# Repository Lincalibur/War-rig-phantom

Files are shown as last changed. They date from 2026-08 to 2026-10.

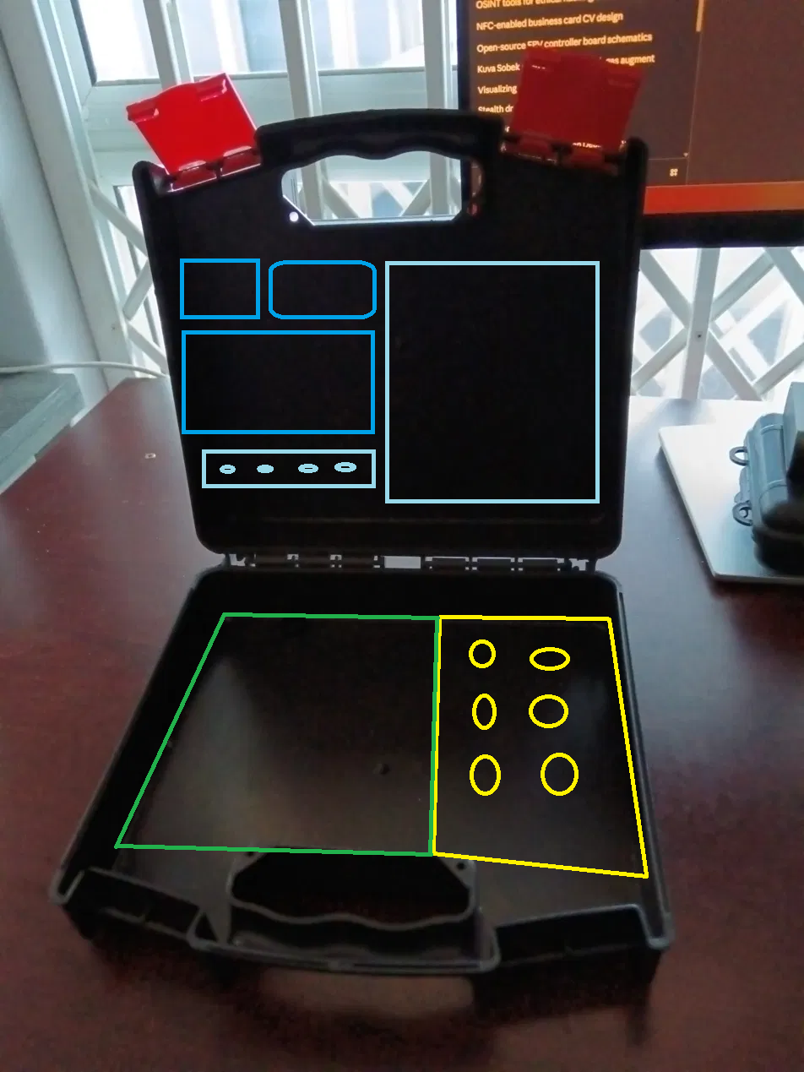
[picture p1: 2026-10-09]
docs/EmptyCase_Edit.png

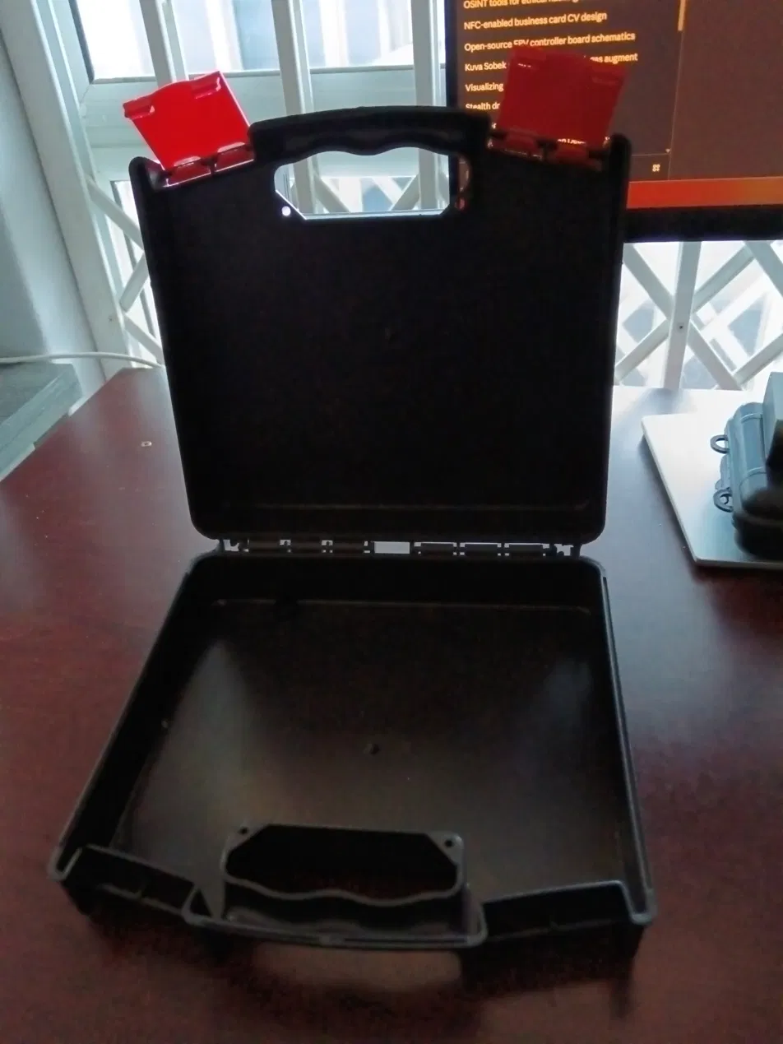
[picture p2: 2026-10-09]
docs/EmptyCase.webp

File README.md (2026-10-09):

<div align="center">

# War-rig-phantom
### *A Portable OPSEC/OSINT Recon Deck*

**Passive WiFi, BLE and sub-GHz listening with GPS-tagged logging, in a 22 cm clamshell case**






**[Build page](https://lincalibur.github.io/War-rig-phantom/)**: boards, case layout, parts checklist and wiring

</div>

---

## Overview

**War-rig-phantom** is a portable counter-surveillance deck built into a 22 × 22 cm clamshell case. Two receive-only ESP32 nodes (WiFi and BLE) and a CC1101 sub-GHz radio feed an ESP32-S3 hub, which logs WiGLE-format CSV to microSD and flags devices that keep following you. Each scan module has its own screen in the lid. A GPS module feeds both nodes, so every sighting carries its own position and time. It runs from a 2S2P 18650 pack. This is the budget v1 build; a Raspberry Pi 5 takes over as hub later.

> **Scope & Ethics**
> Everything in this project is **passive listening and logging.**
> - No deauth transmission
> - No packet injection
> - No touching networks you don't own
>
> This is a recon and awareness tool, not an attack platform.

## Architecture

```
  GPS (NEO-7M) TX --+--> WIFI-NODE  ESP32-C3 ---------------------UART--+
                    +--> BLE-SCAN   ESP32 + built-in 1.9" screen --UART--+
                                                                         v
                         HUB  ESP32-S3: microSD, CC1101 433 MHz, LED + piezo alerts
                                                                         |  row stream
                                                                         v
                         READOUT  Arduino UNO + 3.5" TFT (hub display)

  STATUS  ESP32-C3 + OLED (standalone counters)
  2S2P 18650 -> BMS -> fuse -> master switch -> 5 V buck -> one switch per module
```

The nodes never transmit. They report to the hub over wired UART, which fixes the timing and near-field interference problems that sank the v1 ESP-NOW design. Board names (`HUB`, `READOUT`, `BLE-SCAN`, `WIFI-NODE`, `STATUS`) are defined in [`docs/hardware-layout.md`](docs/hardware-layout.md#board-names).

## Repository

| Path | What's in it |
|---|---|
| [`docs/OVERVIEW.md`](docs/OVERVIEW.md) | **Start here.** Goals, decisions, capabilities, status and next steps |
| [`docs/hardware-layout.md`](docs/hardware-layout.md) | The current build: board names, case layout, power, wiring and parts list |
| [`docs/BOARD-BLE-SCAN-ESP32-1732S019.md`](docs/BOARD-BLE-SCAN-ESP32-1732S019.md) | Spec for the `BLE-SCAN` board |
| [`docs/build-page.html`](docs/build-page.html) | Source of the build page (deployed by `.github/workflows/pages.yml`) |
| [`docs/PCB-BOM-AND-NETLIST.md`](docs/PCB-BOM-AND-NETLIST.md), [`docs/esp32-hub-board.html`](docs/esp32-hub-board.html), [`KiCad Design/`](KiCad%20Design/) | Shelved single-PCB design. The S3 hub pin assignments are still used |
| [`v2/`](v2/README.md) | Firmware and bench prototypes (hub and nodes written, not yet compiled) |
| [`docs/debian-esp32-server-guide.md`](docs/debian-esp32-server-guide.md) | Remote compile/flash station over SSH |

The v1 build (ESP-NOW C3 nodes and an ESP32-1732S019 hub) was removed from the tree. Recover it with `git checkout v1-espnow-archive`.

## Status

| Area | State |
|---|---|
| Case layout and parts list | ✅ planned (2026-10-09); nde3d cart about R1,390 |
| Bench prototypes | ✅ WiFi readout working (C3 scanner to UNO + 3.5" TFT) |
| Power system | ⬜ parts to order; bench test first |
| Firmware | 🟨 hub and nodes written for the old PCB; need retargeting to the boards above, then a first compile |
| Raspberry Pi 5 hub | ⬜ later phase |

## License

See [LICENSE](LICENSE).

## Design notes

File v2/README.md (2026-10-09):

# CyberDeck v2 firmware

Firmware for the clamshell build (plan and wiring in [`../docs/hardware-layout.md`](../docs/hardware-layout.md)). Wired-UART architecture: two receive-only nodes report to an ESP32-S3 hub, and the hub draws on a UNO + 3.5" TFT.

> **Retarget pending.** `hub`, `node_wifi` and `node_ble` were written for the shelved single-PCB design (XIAO C5/C6 nodes, 2.8" ILI9341 on the hub) and have never been compiled. The table below says what each one has to become for budget v1.

## Boards and sketches

Board names are defined in [`../docs/hardware-layout.md`](../docs/hardware-layout.md#board-names).

| Board | Hardware | Sketch today | Work needed for budget v1 |
|---|---|---|---|
| `HUB` | ESP32-S3-DevKitC-1 N16R8 | `hub/` | Replace the ILI9341 UI with a row-stream sender for `READOUT`; add LED + piezo alerts; add CC1101 receive |
| `READOUT` | Arduino UNO R3 + 3.5" TFT shield | `proto_readout_uno/` (working) | None for display. Logging belongs on the `HUB` |
| `WIFI-NODE` | ESP32-C3 | `node_wifi/`; capture code proven in `proto_readout_c3/` | Retarget `node_wifi` to the C3: remove the C5-only band call, set the pins |
| `BLE-SCAN` | ESP32-1732S019 (built-in 1.9" ST7789) | `node_ble/`; detection logic in `proto_tracker_tripwire/` | Port to classic ESP32, add the ST7789 screen (LovyanGFX), prefer NimBLE. Spec: [`../docs/BOARD-BLE-SCAN-ESP32-1732S019.md`](../docs/BOARD-BLE-SCAN-ESP32-1732S019.md) |
| `STATUS` | ESP32-C3 + 128×64 OLED | none yet | New standalone sketch: counters on the OLED |

```
v2/
  shared/deck_link.h        wire protocol: framing, CRC, message structs (nodes + hub)
  shared/deck_node_core.h   node common code: GPS parser, tx queue, UART link, heartbeat
  node_wifi/node_wifi.ino   WIFI-NODE (target: ESP32-C3; code still XIAO C5)
  node_ble/node_ble.ino     BLE-SCAN (target: ESP32-1732S019; code still XIAO C6, no screen)
  hub/hub.ino               HUB, ESP32-S3: tables, WiGLE CSV logging to SD (UI still ILI9341)

  # Bench prototypes (spare parts, no custom PCB) — see "Bench prototypes" below
  proto_readout_c3/         ESP32-C3: WiFi-promiscuous scanner -> streams rows over UART
  proto_readout_uno/        Arduino UNO + 3.5" TFT: renders the readout (pairs with proto_readout_c3)
  proto_link_analyzer/      Arduino UNO: link diagnostic (byte/line/valid-frame stats) — bring-up tool
  proto_tracker_tripwire/   ESP32-S3 + ILI9341: standalone BLE tracker detector (unflashed; source for BLE-SCAN)
```

## Bench prototypes (2026-10-05)

Working counter-surveillance prototypes built from spare parts, independent of the custom PCB.
Wiring reference: [`../docs/proto-readout-wiring.html`](../docs/proto-readout-wiring.html).

**`proto_readout_c3` + `proto_readout_uno` — big-screen WiFi recon readout (WORKING).**
An ESP32-C3 (SuperMini) runs 802.11 promiscuous: APs (beacons/probe-resp), clients (probe-req +
data frames), deauth counting, channel hop 1-13. It keeps the tables and diffs the screen, then
streams `R<rr><c><text>` row-draw commands over a one-way 19200-baud UART to an Arduino UNO +
3.5" TFT, which is a dumb terminal (no tables -> the UNO's 2 KB RAM is never the limit). Clients
are sorted by **persistence** = the longest-shadowing unknown device is the "following me"
candidate. Flash the C3 first (`esp32:esp32:esp32c3:CDCOnBoot=cdc`), then the UNO
(`arduino:avr:uno`); unplug the C3->D0 wire while flashing the UNO.

**`proto_link_analyzer` — UNO link diagnostic.** Flash instead of the readout to measure the link:
bytes/s, lines, valid frames, control-byte (garbage) count, raw stream. Keep for future bring-up.

**`proto_tracker_tripwire` — standalone BLE tracker detector (UNFLASHED).** Runs on the S3 hub
board alone (2.8" ILI9341 + buzzer/LED) and flags AirTag/Find My/Tile/SmartTag by persistence.
BLE here uses Bluedroid; if it's flaky, switch to NimBLE (see learnings).

### Hard-won learnings from bring-up
- **AVR printf has no `*` (dynamic width) support.** `snprintf(..., "%-*.*s", COLS, COLS, s)` renders
  *nothing* on the UNO with no error — it silently broke `drawRow` across many rebuilds and looked
  like a link/power/C3 fault. Use literal widths on AVR: `"%-40.40s"`. (ESP32 printf is fine with `*`.)
- **Pace the UNO link.** The UNO's 64-byte hardware RX buffer overflows if the C3 bursts rows faster
  than the slow parallel TFT can paint them -> corrupted lines. The C3 waits ~150 ms between rows and
  does full refreshes rarely (15 s); normal updates send only the one changed status row.
- **BLE on the ESP32-C3 is unreliable** (Bluedroid + WiFi coexistence on the single radio crashes the
  chip). The C3's prototype role is WiFi-only. For BLE, prefer NimBLE or a separate chip (S3/H2).
- **C3 USB-CDC serial can't be captured** via `arduino-cli monitor` on the debian server — use the
  UNO link as the monitor instead.

## Status: hub and nodes written, NOT compiled, NOT flashed

The bench prototypes above run; `hub`, `node_wifi` and `node_ble` have never been built. Expect a round of compile fixes on the first build. In particular check:
- `esp_wifi_set_band_mode(WIFI_BAND_MODE_AUTO)` in `node_wifi.ino` is C5-only; remove it for the C3.
- The BLE API calls in `node_ble.ino` match your `esp32` core version (core 3.x vs 2.x differ slightly).
- All pin numbers (`DECK_LINK_*`, `DECK_GPS_RX_PIN`, hub `PIN_*`) against the real boards. Hub SPI, CC1101 and node-link pins are in section 3.1 of `../docs/PCB-BOM-AND-NETLIST.md`. Proposed, not yet in code: `WIFI-NODE` link TX=GPIO7, RX=GPIO6, GPS RX=GPIO20; `BLE-SCAN` link TX=GPIO17, RX=GPIO16, GPS RX=GPIO22; `HUB` readout TX=GPIO9, buzzer=GPIO18, alert LED=GPIO21.
- The hub's display pins (GPIO7-10), nav buttons (GPIO38-42) and VBAT sense (GPIO6) belong to the shelved PCB and are unused in this build.

## Build settings

| Sketch | FQBN (arduino-cli) | Notes |
|---|---|---|
| node_wifi | `esp32:esp32:esp32c3:CDCOnBoot=cdc` | `WIFI-NODE`, ESP32-C3. Remove the C5-only `esp_wifi_set_band_mode` call |
| node_ble | `esp32:esp32:esp32` | `BLE-SCAN`, ESP32-1732S019 ("ESP32 Dev Module", 4 MB flash, CH340). UART0 is the USB serial port on this board, so the link and GPS need UART1 and UART2 |
| proto_readout_uno | `arduino:avr:uno` | `READOUT`. Libraries: MCUFRIEND_kbv, Adafruit GFX |
| hub | `esp32:esp32:esp32s3:CDCOnBoot=cdc,PSRAM=opi` | ESP32-S3-DevKitC-1 N16R8 (octal PSRAM; GPIO33-37 unused) |

`CDCOnBoot=cdc` is required on the C3 node: hardware UART0 is used for the GPS, so `Serial` must be USB.

Hub libraries today: `Adafruit GFX Library`, `Adafruit ILI9341`. Both go away once the hub draws on `READOUT`.

## Bring-up order
0. **Power first**: bench-test the 2S pack, charger (8.4 V) and buck (5.1 V) before any board is connected. See `../docs/hardware-layout.md` section 5.
1. **Hub alone**: flash, confirm SD and the `READOUT` link, all pages render with zero data.
2. **One node at a time** on the bench: the node prints a status line over USB every 2 s; connect its UART to the hub and confirm the hub's status page shows LIVE and a non-zero fps.
3. **GPS**: connect the module's TX to both nodes, confirm `gps=fix` on a node's serial output outdoors, then `GPS FIX` on the hub header.
4. **Log check**: drive/walk a short loop, pull the SD, open `/wardrive/wigle_NNNN.csv`, and try a WiGLE upload.

## Wire protocol
See `shared/deck_link.h`. Frame `A5 5A | type | len | payload | crc16`. Nodes report each AP/client/BLE device when it is new, when its info changes, when it is heard ≥6–8 dB stronger, and every 30–45 s while still visible.

## Not implemented yet
- CC1101 sub-GHz (pins reserved on the hub; CS held high).
- LED + piezo alerts and the persistence ("following me") scoring on the hub.
- Pack voltage sensing. The 2S capacity indicator board is the only battery readout for now.
- 802.15.4 (Zigbee/Thread): no board in this build has that radio.

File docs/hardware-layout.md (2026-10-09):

# Hardware layout

Physical layout plan for the cyberdeck: a portable, passive counter-surveillance station built into a 22 × 22 cm clamshell case. Scan modules each run on their own screen in the lid, a hub coordinates them, and the base holds power, switching and the RF hardware.

The build is in two phases:

| Phase | Hub | Status |
|---|---|---|
| **Budget v1 (current)** | ESP32-S3-DevKitC-1 N16R8, using the 3.5" screen as its display | Parts in the nde3d cart, 2026-10-09 |
| **Later upgrade** | Raspberry Pi 5 + 5" display + USB hub + SDR | Deferred on cost; nde3d doesn't stock any of it |

Cyberdeck layout: lid, base and side section

> The drawing shows budget v1. In the Pi phase the blank plate becomes the 5" hub screen, and the two bays under the deck hold the Pi 5 and the USB hub + SDR.
>
> All dimensions are approximate planning figures. Measure the case interior and check every part against its datasheet before cutting anything.

---

## Board names

Every board has one fixed name. Use it in docs, firmware comments and on a label stuck to the board itself.

| Name | Board | Job | Reference |
|---|---|---|---|
| `HUB` | ESP32-S3-DevKitC-1 N16R8 | Brain: collects node reports, logs to SD, runs the CC1101, drives alerts | Pins: [`PCB-BOM-AND-NETLIST.md`](PCB-BOM-AND-NETLIST.md) section 3.1 |
| `READOUT` | Arduino UNO R3 + 3.5" TFT shield | Hub display (dumb terminal for the `HUB`) | [`proto-readout-wiring.html`](proto-readout-wiring.html) |
| `BLE-SCAN` | ESP32-1732S019 (classic ESP32 + built-in 1.9" screen) | Scan 2: BLE trackers | [`BOARD-BLE-SCAN-ESP32-1732S019.md`](BOARD-BLE-SCAN-ESP32-1732S019.md) |
| `WIFI-NODE` | ESP32-C3 (first one) | Headless WiFi promiscuous scanner | `v2/proto_readout_c3` |
| `STATUS` | ESP32-C3 (second one) + 128×64 OLED | Scan 3: status and counters | — |

---

## 1. Case

| Property | Value |
|---|---|
| Outer footprint | ~220 × 220 mm |
| Total height (closed) | ~70 mm |
| Depth per half | ~35 mm (lid and base are equal) |
| Handle recess | Top-centre of lid and front-centre of base, ~90 × 35 mm each |
| Hinge | Rear edge, full width |
| Anchor points | Moulded centre boss in each half |

**Usable interior per half:** roughly 205 × 165 mm once the handle recess and wall thickness are taken off.

---

## 2. Lid: displays and I/O

| Zone | Approx. size | Budget v1 | Later (Pi phase) |
|---|---|---|---|
| Top-left | 35 × 35 mm | 128×64 OLED + ESP32-C3: Scan 3, status/counters | Same |
| Top-middle | 55 × 40 mm | ESP32-1732S019 (built-in 1.9" 170×320): Scan 2, BLE trackers | Same |
| Middle-left | 85 × 56 mm | Arduino UNO + 3.5" TFT shield: **hub display**, fed by the S3 | Scan 1: main scan view |
| Bottom-left | ~117 × 22 mm | microSD shield slot, alert LED + piezo, mute button | Port panel: USB-A, USB-C, microSD |
| Right | ~77 × 121 mm | Empty (blank plate). GPS module mounts here, patch antenna facing out | 5" hub display, portrait |
| Hinge edge | ~25 mm strip | Cable slack zone | Same |

**Mounting:** a 3 mm faceplate with cut-outs for each screen, screwed to the lid's centre boss plus 4 corner standoffs (M3 nylon kit). Use acrylic or a 3D print, **not aluminium**: the ESP32 antennas sit behind the plate and metal would shield them.

**To measure before cutting:**
- The ESP32-1732S019 board outline against the 55 × 40 mm zone; the board is longer than its screen.
- The UNO + shield stack height. It is roughly 25–30 mm against the 23 mm lid budget in §4. It closes over the power zone, so keep that part of the deck clear.
- Feed the UNO through its 5 V pin. A USB-B plug won't fit behind the faceplate.

---

## 3. Base: power, switching and compute

### Top layer (deck plate)

| Zone | Contents |
|---|---|
| Rear strip | Hinge cable entry; CC1101 antenna (later: SMA jacks through the wall) |
| Left (green) | Power zone: master switch + panel fuse holder on top |
| Right (yellow) | Section switch panel: 6 mini toggles |
| Front-left pocket | Charge input: 5.5 × 2.1 mm DC jack (12 V in) |
| Front-centre | Handle recess (keep clear) |
| Front-right pocket | Battery capacity indicator (2S) |

### Below deck (electronics bay)

| Location | Budget v1 | Later (Pi phase) |
|---|---|---|
| Under power zone | 2S2P 18650 pack in a 4-cell holder, 2S BMS, 5 V buck, XL4015 charger | Same, plus a second buck for the lid rail |
| Under switch panel | Wiring only; keep ~15 mm clear for switch bodies | Same |
| Front-left bay | `HUB`: ESP32-S3 + CC1101 | Raspberry Pi 5 (85 × 56 mm), low-profile cooling |
| Front-right bay | `WIFI-NODE`: ESP32-C3 (headless) | Powered USB hub + SDR dongle |

Keep the CC1101 and the WiFi node away from the buck converter and the charger.

---

## 4. Depth budget (case closed)

When the case closes, the lid screens face down onto the deck, so both stacks must fit together.

| Layer | Thickness |
|---|---|
| Lid shell | 3 mm |
| ESP32 + driver boards | 15 mm |
| Screen modules | 8 mm |
| Gap to lid rim | 9 mm |
| *— split line —* | |
| Space above deck | 7 mm |
| Deck plate | 3 mm |
| Electronics bay | 22 mm |
| Base floor | 3 mm |
| **Total** | **~70 mm** |

The deck sits 3 mm higher than first drawn: an 18650 in a holder is about 21 mm tall and did not fit the original 19 mm bay.

**Rule:** switch caps + screen bezel protrusion must stay under ~16 mm combined, or the lid won't close.

---

## 5. Systems

### Power (budget v1)

```
12 V adapter ─► DC jack ─► XL4015 CC/CV (8.4 V, ~1 A) ─┐
                                                       ▼
18650 2S2P pack ◄─► 2S 20 A BMS ─► Fuse (8 A) ─► Master switch ─► 5 A buck (5.1 V) ─┬─► Hub (S3 + SD + CC1101 + GPS)
        │                                                                          ├─► Hub display (UNO + 3.5")
        └─► Capacity indicator (2S)                                                ├─► Scan 2 (ESP32-1732S019)
                                                                                   ├─► Scan 3 (C3 + OLED)
                                                                                   ├─► WiFi node (C3)
                                                                                   └─► Aux
```

- Load is about 1–1.5 A at 5 V, so the single buck runs everything. Runtime should be roughly 3–4 hours; measure it, because the cells are probably below their labelled 2200 mAh.
- Each branch has its own section switch so unused modules draw nothing.
- **Before connecting anything:** check the 4-cell holder with a multimeter and rewire it to 2S2P if it arrives as 4S (~15 V). Set the XL4015 to 8.4 V and the buck to about 5.1 V with no load.
- Charging is through the DC jack only. The single-cell USB-C charge/boost boards (IP5310, 5 V 2 A) **must never be connected to this pack**.
- The DC jack is rated 3 A; keep the XL4015 current limit at about 1 A.

**Pi phase changes:** the Pi 5 gets the 5 A buck to itself and the lid modules get a second buck. Add a momentary shutdown button on the Pi's power header (cutting power corrupts the SD card), set `usb_max_current_enable=1`, and confirm the master switch is rated 5 A DC or more.

### Section switch map

| Switch | Budget v1 | Later (Pi phase) |
|---|---|---|
| Master (power zone) | Everything, after the fuse | Same |
| 1 | Hub: S3 + SD + CC1101 + GPS | Pi 5 + 5" screen |
| 2 | Hub display: UNO + 3.5" TFT | Scan 1 |
| 3 | Scan 2: ESP32-1732S019 | Scan 2 |
| 4 | Scan 3: C3 + OLED | Scan 3 |
| 5 | WiFi node: C3 | RF/SDR: USB hub + SDR |
| 6 | Aux (spare) | Aux |

### Data (budget v1)

```
NEO-7M GPS TX ─┬─► WIFI-NODE (ESP32-C3) ──UART──┐
               └─► BLE-SCAN (ESP32-1732S019) ─UART─┴─► HUB (ESP32-S3) ──row stream (one-way UART)──► READOUT (UNO + 3.5" TFT)
                                                            │
                                                            ├─ SPI: microSD shield (logging), CC1101 (433 MHz)
                                                            └─ LED + piezo alerts, mute button
```

- All links are wired 3.3 V UART; nodes are receive-only radios. Framing is `v2/shared/deck_link.h`. S3 pins follow section 3.1 of [`PCB-BOM-AND-NETLIST.md`](PCB-BOM-AND-NETLIST.md).
- The hub display reuses the `R<rr><c><text>` row-stream protocol from `v2/proto_readout_c3` / `proto_readout_uno`; the S3 takes over the sender role from the C3.
- The GPS TX line fans out to both nodes, as the existing node firmware expects (`v2/shared/deck_node_core.h`): each node stamps its own sightings and the `HUB` takes position and time from their reports.
- The S3's three hardware UARTs are one per node link plus one for the `READOUT` stream. `STATUS` (C3 + OLED) runs standalone in v1; the `READOUT` UART's unused RX pin is free if it later needs a link.
- Put a ~1 kΩ series resistor on each UART line between separately switched modules, so a powered board can't back-feed an unpowered one through its I/O pins.
- The CH340E USB-TTL adapter is a bring-up tool: it captures C3 serial output (C3 USB-CDC capture has been unreliable) and later connects the GPS to the Pi.

**Pi phase changes:** the ESP32s connect to the Pi over USB serial through a powered hub. A board on the hub is powered through its USB cable, so section switches must then switch each cable's VBUS line (or use a hub with per-port switches) rather than a separate 5 V feed.

### RF and antennas

- Everything is passive receive. No deauth, injection or jamming.
- CC1101 (433 MHz) uses its spring antenna or an IPEX lead to the rear wall.
- GPS patch antenna faces out of the lid, away from the buck and charger.
- Later: SMA bulkhead jacks for the SDR. Fit them to a side wall if antennas would foul the open lid.
- Optional: copper tape shield over the buck converter.

### Thermal

Budget v1 needs no cooling. For the Pi phase the official active cooler is borderline in the bay; use a low-profile heatsink case or mount the Pi on the floor with the cooler through a deck cut-out, and cut a small vent grille near it.

---

## 6. Cable routing across the hinge

Only these should cross the hinge:

1. Switched 5 V feeds and ground to the lid modules
2. UART lines (BLE node → hub, hub → display)
3. GPS, SD and alert wiring, if those sit in the lid

Use the 10 mm mesh sleeve, leave a slack loop in the lid's hinge strip, and strain-relieve both ends. SPI to the SD shield is the one fast bus; keep that run short or mount the shield in the base.

---

## 7. Parts list

### 7.1 On hand

| Part | Role |
|---|---|
| Arduino UNO R3 + 3.5" 480×320 TFT shield | Hub display |
| ESP32-1732S019 (ESP32 + 1.9" ST7789) | Scan 2, BLE |
| ESP32-C3 ×2 | WiFi node; Scan 3 |
| 128×64 OLED | Scan 3 |
| Active/passive buzzers, LEDs, 12 mm push buttons | Alerts and mute |
| Master switch (toolbox spare) | Check rating before the Pi phase |
| Second UNO, breadboards, jumpers, resistors | Bring-up |

### 7.2 nde3d cart (2026-10-09)

| Part | Qty | Price | Role |
|---|---|---|---|
| [ESP32-S3-DevKitC-1 N16R8](https://nde3d.co.za/esp-devices/3511-esp32-s3-n16r8-devkitc-development-board-with-wireless-53-16mb-flash-8mb-ram-type-c-usb.html) | 1 | R188.86 | Hub |
| [CC1101 433 MHz, IPEX](https://nde3d.co.za/rf-modules/2959-433mhz-cc1101-wireless-rf-transceiver-module.html) | 1 | R114.00 | Sub-GHz receive |
| [GY-NEO-7M GPS](https://nde3d.co.za/rf-modules/3191-gy-neo-7m-gps-active-ceramic-antenna-module.html) | 1 | R136.48 | Position and time |
| [Micro TF/SD shield for D1 Mini](https://nde3d.co.za/modules/779-micro-tfsd-card-shield-for-d1-mini.html) | 1 | R24.00 | Logging |
| [CH340E Type-C USB-TTL](https://nde3d.co.za/interface-converters/971-ch340e-micro-usb-to-ttl-serial-converter-5v33v.html) | 1 | R42.00 | Bring-up; GPS to Pi later |
| [18650 2200 mAh Li-ion](https://nde3d.co.za/consumables/2977-37v-18650-1500mah-lithium-ion-battery.html) | 4 | R317.60 | 2S2P pack |
| [18650 holder ×4 with wires](https://nde3d.co.za/battery-holders/2635-18650-battery-holder-x4-with-wires.html) | 1 | R16.00 | Pack; rewire to 2S2P |
| [2S 20 A BMS](https://nde3d.co.za/interface-converters/2777-2s-20amp-battery-management-circuit-bms.html) | 1 | R75.00 | Protection + balancing |
| [5 A 75 W step-down module](https://nde3d.co.za/power-supplies/2428-5a-75w-dc-dc-high-power-adjustable-step-down-stabilized-voltage-supply-module.html) | 1 | R118.00 | 5 V rail |
| [XL4015 5 A CC/CV](https://nde3d.co.za/power-supplies/1258-5a-30v-adjustable-voltage-and-current-charger.html) | 1 | R66.00 | Charger, set to 8.4 V |
| [3 A 5.5 × 2.1 mm bulkhead DC connector](https://nde3d.co.za/plugs-sockets-connectors/2096-3a-55-x-21mm-bulkhead-male-dc-power-connector.html) | 1 | R4.67 | Charge input |
| [Fuse holder, 5×20 mm panel mount](https://nde3d.co.za/plugs-sockets-connectors/2499-fuse-holder-for-5x20mm-panel-mount.html) | 1 | R25.00 | Main fuse |
| [5×20 mm glass fuse 8 A](https://nde3d.co.za/fuses/2853-5-x-20mm-glass-fuse-250v-8a.html) | 5 | R15.00 | Main fuse + spares |
| [Miniature toggle SMTS-203 (DPDT)](https://nde3d.co.za/switches/2890-miniature-toggle-switch-on-off-on-smts-203-dpdt.html) | 6 | R84.00 | Section switches |
| [Capacity indicator board, 2S](https://nde3d.co.za/electronics/2574-12v-lithium-battery-power-indicator-board.html) | 1 | R58.00 | Battery meter |
| [Mesh nylon sleeve 10 mm × 1 m](https://nde3d.co.za/cable/3036-1-metre-flame-retardant-nylon-pet-mesh-telescopic-sleeve.html) | 1 | R7.00 | Hinge bundle |
| [M3 nylon standoff kit, 180 pcs](https://nde3d.co.za/bolts-nuts/3354-sdafasdf.html) | 1 | R98.78 | Mounting |
| **Total** | | **R1,390.39** | |

Also in the cart but **not used in this build** (single-cell boards, R116): IP5310 Type-C 3 A charge/boost module ×1, 5 V 2 A charge/boost module ×2.

### 7.3 Still needed for budget v1

- 12 V DC adapter with a 5.5 × 2.1 mm plug, 1 A or more
- 3 mm acrylic or printed faceplate and deck plate
- Hook-up wire (18–20 AWG for the power path), cable ties

### 7.4 Later (Pi phase, other suppliers)

| Part | Note |
|---|---|
| Raspberry Pi 5 + microSD + low-profile cooler | |
| 5" display, DSI touch preferred | Check outline against the 77 × 121 mm zone |
| Powered USB hub, 7+ ports | Per-port switches preferred |
| RTL-SDR, SMA bulkheads, pigtails, antennas | |
| Second 5 V buck | Lid rail |
| 2S USB-C charger module | Replaces DC-jack charging, optional |
| Shutdown push button | |
| nde3d: [USB-A panel extension](https://nde3d.co.za/plugs-sockets-connectors/1725-1mtr-usb-extension-cable-panel-mount-type-a.html) R33, [Type-C extension](https://nde3d.co.za/cable/3484-type-c-31-male-to-female-usb-extension-cable-with-screw-ear.html) R123, [microSD extender](https://nde3d.co.za/connectors/3513-microsd-card-extender.html) R84 | Port panel |

The Pi 5 has no 3.5 mm jack, so audio on the port panel would need a USB audio adapter.

---

## 8. Build order

- [ ] Measure the case interior precisely and update this doc
- [ ] Order the nde3d cart (§7.2)
- [ ] Make cardboard templates of the lid faceplate and base deck; test-fit with the case closed
- [ ] Build and test the power system on the bench: holder wiring, BMS, fuse, charger at 8.4 V, buck at 5.1 V, switches
- [ ] Bring up the S3 hub on the bench: SD, GPS, one node at a time, then the UNO display link
- [ ] Cut faceplate and deck plate; cut the DC jack and meter openings in the front pockets
- [ ] Mount the screens and modules; route the hinge bundle
- [ ] Full close test: confirm nothing touches when the lid shuts
- [ ] Walk test, log check, runtime measurement

---

## 9. Open questions

- Exact inner dimensions of each half
- Whether `STATUS` stays standalone or gets a link to the hub (one UART RX pin is free)
- Current rating of the SMTS-203 toggles (not in the listing); matters once a Pi draws 4–5 A through one
- Pi location when it arrives: base (as drawn) or behind the hub screen in the lid

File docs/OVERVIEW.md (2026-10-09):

# CyberDeck v2 — overview

Start here. This covers what the deck does, the hardware decisions and why they were made, and where everything else lives.

> **Current plan (2026-10-09): clamshell build, no custom PCB.** The deck is now a 22 × 22 cm clamshell case with one screen per scan module, hand-wired from modules. Budget v1 uses the ESP32-S3 as hub; a Raspberry Pi 5 replaces it later. The physical layout, power system, data links and parts list are in [`hardware-layout.md`](hardware-layout.md), which wins where it differs from this page. The single-PCB design described under "Board" below is shelved; its S3 pin assignments are still used.

| Need | Go to |
|---|---|
| **Current build: layout, power, wiring, parts list** | [`hardware-layout.md`](hardware-layout.md) |
| Board names (`HUB`, `READOUT`, `BLE-SCAN`, `WIFI-NODE`, `STATUS`) | [`hardware-layout.md`](hardware-layout.md#board-names) |
| `BLE-SCAN` board spec (ESP32-1732S019: pins, display config, build settings) | [`BOARD-BLE-SCAN-ESP32-1732S019.md`](BOARD-BLE-SCAN-ESP32-1732S019.md) |
| S3 hub pin assignments (and the shelved PCB BOM) | [`PCB-BOM-AND-NETLIST.md`](PCB-BOM-AND-NETLIST.md) |
| Build page on GitHub Pages: boards, layout, parts checklist, wiring | [`build-page.html`](build-page.html), deployed to <https://lincalibur.github.io/War-rig-phantom/> |
| Shelved single-PCB interactive page | [`esp32-hub-board.html`](esp32-hub-board.html) (deployed as `pcb-v2.html`) |
| KiCad project | [`../KiCad Design/`](../KiCad%20Design/) |
| Firmware, build settings, bring-up order | [`../v2/README.md`](../v2/README.md) |
| Remote flashing station | [`debian-esp32-server-guide.md`](debian-esp32-server-guide.md) |

The v1 ESP-NOW build (C3 nodes, ESP32-1732S019 hub) was removed from the tree. It is kept in git under the tag `v1-espnow-archive`.

## Goal
A portable counter-surveillance deck that scans and logs the radio environment around you and flags devices that keep following you: WiFi networks and devices, BLE devices and trackers, and sub-GHz signals. Every sighting is GPS-tagged. The case is a **22 × 22 × 7 cm clamshell**.

**Everything here is passive listening.** Don't add deauth, injection or jamming features.

## Architecture (budget v1)

```
  NEO-7M GPS TX --+--> WIFI-NODE (ESP32-C3) ----------UART--+
                  +--> BLE-SCAN (ESP32-1732S019, 1.9") -UART--+--> HUB (ESP32-S3) --row stream--> READOUT (UNO + 3.5" TFT)
  STATUS (ESP32-C3 + OLED, standalone)                              |  SPI: microSD, CC1101 433 MHz
                                                                    |  LED + piezo alerts
  2S2P 18650 -> BMS -> fuse -> master switch -> 5 V buck -> section switch per module
```

The GPS still fans out to both nodes, and the hub's display is the UNO + 3.5" shield already on hand. Details are in [`hardware-layout.md`](hardware-layout.md).

## Architecture (original single-PCB design, shelved)

```
                 GPS TX (NEO-7M) ------+----------------+
                                       |                |
                            +----------v-----+  +-------v--------+
                            | ESP32-C3 PRO   |  | ESP32-H2       |
                            | Mini: WiFi     |  | SuperMini: BLE |
                            | 2.4 GHz        |  | (+802.15.4)    |
                            +-------+--------+  +-------+--------+
                                    | UART              | UART   (wired, 3.3 V)
                            +-------v-------------------v--------+
                            |  ESP32-S3-DevKitC-1 N16R8 (hub)    |
                            |  SPI: 2.8" ILI9341, microSD,       |
                            |       CC1101 433 MHz               |
                            |  5-way nav, VBAT sense on GPIO6    |
                            +------------------------------------+
  18650 -> IP5310 board -> SW_PWR -> 5V_RAIL -> each module (via its own Schottky)
```

The key idea is that **nodes never transmit**. They are receive-only scanners that report over wired UART. That removes the ESP-NOW timing problems and the near-field desense that broke v1. Each node reads the GPS directly, so it tags its own sightings with position and time.

## Decisions

| Date | Decision | Why |
|---|---|---|
| 2026-09-20 | Fresh start as one KiCad PCB | The ESP-NOW build never worked reliably with both nodes active |
| 2026-09-20 | Wired UART instead of ESP-NOW | Nodes stay receive-only, so there's no timing or near-field interference |
| 2026-09-20 | ESP32-S3 hub with a separate 2.8" SPI TFT | More GPIO and RAM than the ESP32-1732S019, plus a bigger screen |
| 2026-09-20 | GPS fanned out to both nodes | Every sighting carries its own location |
| 2026-09-20 | CC1101 on the hub SPI bus | Replaces the faulty RXB6 sub-GHz receiver |
| 2026-09-20 | Ready-made power module, no custom charge/boost stage | Power is the part most likely to cause random resets |
| 2026-09-20 | WiGLE-format CSV on microSD | Uploadable to wigle.net |
| 2026-09-25 | Source everything from nde3d.co.za | One South African supplier. This forced the substitutions below |
| 2026-10-05 | Reposition as a counter-surveillance tool | "Am I being followed" scoring on top of the same passive radios; LED + piezo alerts |
| 2026-10-09 | 22 × 22 cm clamshell, one screen per scan module, no custom PCB | Bigger case on hand; modules and screens already owned; hand-wiring avoids a PCB order |
| 2026-10-09 | ESP32-S3 stays the hub for budget v1; Raspberry Pi 5 later | The Pi 5, 5" display, USB hub and SDR are too expensive for now and nde3d stocks none of them |
| 2026-10-09 | 2S2P 18650 + BMS + 5 V buck replaces the IP5310 single-cell stage | Sized so a Pi 5 can be added without rebuilding the power system. Charging is via a DC jack and an XL4015 at 8.4 V, because nde3d has no 2S USB-C charger |
| 2026-10-09 | No 2.8" ILI9341; the hub draws on the UNO + 3.5" shield | Saves R468 and reuses the working row-stream readout |

**nde3d substitutions (2026-09-25).** Full detail is in section 1.4 of `PCB-BOM-AND-NETLIST.md`.
- WiFi node: ESP32-C3 PRO Mini replaces the XIAO C5. That means **no 5 GHz**; most dual-band APs still beacon on 2.4 GHz.
- BLE node: ESP32-H2 SuperMini replaces the XIAO C6. If H2 BLE misbehaves in Arduino, fall back to a C3 SuperMini.
- Power: an IP5310 power-bank board plus an 18650 replaces the PowerBoost 1000C and LiPo. The IP5310 has no EN or LBO pin, so the power switch sits on the 5 V output and low battery comes from a VBAT divider on GPIO6.
- Buttons: a 5-way nav module replaces five tactile switches.
- GPS: NEO-7M. CC1101: 433 MHz for South Africa.

## What the radios can and can't do
- **WiFi (C3):** promiscuous mode captures management frames and data-frame headers. That covers APs (SSID, BSSID, channel, encryption, vendor, hidden SSIDs, RSSI), clients (MAC, probed SSIDs, random-MAC detection) and client-to-AP links. It listens on one channel at a time and hops. It's 2.4 GHz only.
- **BLE (H2):** advertisement scanning gives MAC, RSSI, name, manufacturer ID and tracker detection (AirTag / Find My / Tile). It can't do Classic Bluetooth. 802.15.4 (Zigbee/Thread) is possible later.
- **Sub-GHz (CC1101, 433 MHz):** OOK/ASK/FSK reception. Not implemented in firmware yet.
- **Not possible here:** true wideband spectrum analysis, LoRa decoding, ADS-B or cellular. Those need an RTL-SDR, which sits outside this board.

## Board (shelved)
The single-PCB design below is kept for reference. The current build is hand-wired in the clamshell case.

- **2 layers with a solid ground plane** on the bottom, never split. Everything is socketed: every module plugs into female headers so it can be swapped and reflashed.
- **Placement:** the hub and display go on the top face. The nodes, CC1101, IP5310 and battery go on the bottom face.
- **RF placement:** the GPS goes on the top edge with no copper under its patch. The WiFi and BLE nodes go at opposite short edges, with antenna keep-outs running to the board edge. The CC1101 antenna goes at an edge away from the nodes.
- **Power traces:** 5V_RAIL at least 1 mm wide, and at least 1.5 mm from the IP5310 to C1. Place each bulk cap right at the pin it feeds.
- **USB-C access:** every module's USB-C port must be reachable from the case edge for flashing.
- **Board size is not settled yet.** `PCB-BOM-AND-NETLIST.md` says 100 x 150 mm (portrait). The layout concept in `esp32-hub-board.html` is drawn at 170 x 100 mm. Pick one before routing.

## Power budget
These figures are for the shelved IP5310 design. The current power system is in [`hardware-layout.md`](hardware-layout.md) section 5; the 3.3 V note below still applies to the S3 hub.

- **5 V:** about 900 mA to 1 A peak (WiFi node ~250–300 mA, BLE node ~150 mA, S3 plus its 3V3 loads ~300–350 mA, display ~100 mA). The IP5310 board is rated 3.1 A. **The mini slide switch is the weak point:** many are rated only 0.3–0.5 A, so buy one rated 1 A or more.
- **3.3 V:** the S3 devkit's onboard LDO (~800 mA) feeds the display, GPS, CC1101 and SD, which puts it close to the limit at peak. If the hub browns out, give the display and SD their own 3.3 V regulator.
- Bench-test the IP5310 for charge-while-running (a possible brief dropout) and for idle auto-shutdown.

## Status (2026-10-09)
- **Hardware:** clamshell layout planned in `hardware-layout.md`; the nde3d cart for budget v1 (about R1,390) is listed there. The PCB and KiCad work are shelved.
- **Working on the bench:** the WiFi readout (`proto_readout_c3` + `proto_readout_uno`: C3 promiscuous scanner streaming rows to the UNO + 3.5" TFT).
- **Firmware** (`../v2/`): `hub`, `node_wifi` and `node_ble` are written but **never compiled or flashed**, and still carry XIAO C5/C6 pin labels. Needed for budget v1:
  - `hub.ino`: replace the ILI9341 UI with the row-stream sender for the UNO display; LED + piezo alerts.
  - `node_wifi`: retarget to the ESP32-C3 (remove the C5-only band call, remap pins).
  - BLE node: port to the ESP32-1732S019 with its ST7789 screen (start from `proto_tracker_tripwire`).
  - Not implemented yet: CC1101 reception, pack voltage sensing.

## Next steps
1. Order the cart; measure the case interior and make cardboard templates.
2. Bench-build and test the power system before it goes near the electronics (see `hardware-layout.md` section 5).
3. Get the hub compiling on the S3, then bring up SD, GPS, one node at a time, then the UNO display link.
4. Cut the faceplate and deck, mount everything, and do the close test.
5. Walk test and a WiGLE upload. Add the Raspberry Pi 5 phase when budget allows.

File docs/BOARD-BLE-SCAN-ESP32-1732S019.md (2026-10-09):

# BLE-SCAN board: ESP32-1732S019

**Deck name: `BLE-SCAN`.** This is the classic ESP32 board with the built-in 1.9" colour screen, bought from nde3d. In the deck it is the Scan 2 module: BLE tracker detection on its own screen, reporting to the `HUB` over UART. All board names are listed in [`hardware-layout.md`](hardware-layout.md#board-names).

Earlier notes also call this board "the ESP-32S with the attached screen" and "the prototype hub". It is the same board. It is **not** the hub any more; the hub is the ESP32-S3.

Source: nde3d's product sheet, kept as [`ESP32-1732S019_Datasheet.pdf`](ESP32-1732S019_Datasheet.pdf). The sections marked "deck" are this project's own choices.

## Specifications

| Item | Value |
|---|---|
| Microcontroller | ESP32-D0WD-V3, dual-core Xtensa LX6, up to 240 MHz |
| Flash | 4 MB |
| PSRAM | None |
| WiFi | 2.4 GHz 802.11 b/g/n |
| Bluetooth | Classic (BR/EDR) and BLE |
| Display | 1.9" IPS TFT, 170 × 320 px, non-touch |
| Display driver | ST7789, 4-wire SPI |
| USB | Type-C, CH340 USB-to-serial |
| Logic level | 3.3 V |
| Power input | 5 V via USB-C |
| Onboard extras | BOOT and EN buttons only. No SD slot |

This is the classic ESP32 version of the board, not the ESP32-S3 version.

## Display pins (fixed on the board)

| Signal | GPIO |
|---|---|
| SCLK | 14 |
| MOSI | 13 |
| MISO | not connected |
| CS | 15 |
| DC | 2 |
| RST | tied to EN (use -1 in software) |
| Backlight | 21 |

- **Backlight:** drive GPIO 21 high with a plain `digitalWrite`. Don't use PWM; it has a known issue on recent ESP32 cores.
- **Free GPIOs:** 4, 16, 17, 22, 25, 26, 27, 32, 33.
- **Never use GPIO 6–11:** they are the onboard flash.

## Deck wiring (planned)

| Function | GPIO | Connects to |
|---|---|---|
| Link TX | 17 | `HUB` BLE_LINK_RX (S3 GPIO1), through ~1 kΩ |
| Link RX | 16 | `HUB` BLE_LINK_TX (S3 GPIO2), through ~1 kΩ |
| GPS RX | 22 | NEO-7M TX (shared with `WIFI-NODE`) |
| 5 V | 5 V pin | Section switch 3 |
| GND | GND | Common ground |

GPIO 16/17 are the ESP32's default UART2 pins. The remaining free GPIOs (4, 25, 26, 27, 32, 33) are spare for a local alert LED, buzzer or button. These assignments are a plan and have not been wired or tested.

## Arduino build settings

| Setting | Value |
|---|---|
| Board | ESP32 Dev Module (`esp32:esp32:esp32`) |
| Flash size | 4 MB |
| Upload speed | 921600; drop to 115200 if uploads fail |
| Driver | CH340 |

If an upload fails with "Failed to connect / wrong boot mode": hold BOOT, tap EN, release BOOT, then upload again.

## Display library configuration

nde3d recommends LovyanGFX. The whole pin configuration lives in the sketch.

```cpp
#define LGFX_USE_V1
#include <LovyanGFX.hpp>

class LGFX : public lgfx::LGFX_Device {
  lgfx::Panel_ST7789 _panel;
  lgfx::Bus_SPI      _bus;
public:
  LGFX() {
    { auto c = _bus.config();
      c.spi_host   = SPI2_HOST;   // HSPI
      c.spi_mode   = 0;
      c.freq_write = 40000000;
      c.pin_sclk   = 14;
      c.pin_mosi   = 13;
      c.pin_miso   = -1;
      c.pin_dc     = 2;
      _bus.config(c); _panel.setBus(&_bus); }
    { auto c = _panel.config();
      c.pin_cs   = 15;
      c.pin_rst  = -1;            // reset tied to EN
      c.panel_width  = 170;
      c.panel_height = 320;
      c.offset_x = 35;            // 170-wide panel offset
      c.offset_y = 0;
      c.invert   = true;          // IPS panel
      c.rgb_order = false;
      _panel.config(c); }
    setPanel(&_panel);
  }
};
LGFX tft;

void setup() {
  pinMode(21, OUTPUT);
  digitalWrite(21, HIGH);         // backlight on
  tft.init();
  tft.setRotation(1);             // landscape, 320 x 170
  tft.fillScreen(TFT_BLACK);
  tft.setTextColor(TFT_WHITE);
  tft.drawString("Hello!", 10, 10);
}
void loop() {}
```

- If red and blue look swapped, change `rgb_order`.
- If the image is shifted sideways, adjust `offset_x`.

## Limits that matter for the deck

- **4 MB flash, no PSRAM:** keep device tables small, and prefer NimBLE over Bluedroid to save flash and RAM.
- **No SD slot:** it cannot log on its own; logging happens on the `HUB`.
- **No touch and no user buttons:** any input needs a button on a free GPIO.
- **Board outline is not in the product sheet.** Measure it before cutting the 55 × 40 mm lid zone.

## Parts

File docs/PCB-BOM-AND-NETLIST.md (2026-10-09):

# CyberDeck v2 — exact BOM and netlist (KiCad input)

> **Shelved 2026-10-09.** The build moved to a hand-wired 22 × 22 cm clamshell case with a 2S battery system; the current parts list is in [`hardware-layout.md`](hardware-layout.md) section 7. This PCB BOM (section 1) and power tree (section 2) no longer describe what is being built. **Still in use:** the S3 hub pin assignments in section 3.1 for SPI, microSD, CC1101 and the node UART links. The display, nav-button and GPIO6 VBAT-divider nets do not apply (the divider was sized for one cell; a 2S pack needs different values).

Authoritative parts list and pin-by-pin connections for the 100 x 150 mm board. Where any other doc differs from this one, **this file wins** (see `OVERVIEW.md` for the why). As of the 2026-09-25 nde3d revision, the node boards changed (C3 PRO Mini / H2 SuperMini), so the firmware in `../v2/` still has XIAO pin labels and needs updating to match.

Items marked **[VERIFY]** are footprint/pinout facts recalled from memory of the manufacturer's documentation. Check each against the datasheet or the physical board before sending the PCB to fabrication.

## 1. Components

**Revision 2026-09-25: sourced from nde3d.co.za (Next Dimension Electronics).** nde3d doesn't stock the XIAO C5/C6, the PowerBoost 1000C, LiPo pouch cells, 6x6 tactile switches or PTC fuses, so those were substituted. Section 1.4 says what changed and why. Prices are as nde3d listed them on 2026-09-25.

### 1.1 Modules (all plug into socket headers; nothing is soldered down)

| Ref | Part | Qty | Board-side footprint | Notes |
|---|---|---|---|---|
| U1 | ESP32-S3-DevKitC-1 **N16R8**, [nde3d](https://nde3d.co.za/esp-devices/3511-esp32-s3-n16r8-devkitc-development-board-with-wireless-53-16mb-flash-8mb-ram-type-c-usb.html) R188.86 | 1 | 2x 1x22 female 2.54 mm, rows ~22.86 mm apart **[VERIFY]** | Hub. The octal PSRAM uses GPIO33-37, which this netlist already leaves free. In Arduino, set PSRAM = "OPI PSRAM" |
| U2 | ESP32-C3 PRO Mini (ceramic antenna + IPEX), [nde3d](https://nde3d.co.za/esp-devices/3722-esp32-c3-supermini-wifi-bluetooth-compatible-board-supermini-development-board-development-board-core-board-for-arduino.html) R110 | 1 | 2x 1x8 female 2.54 mm, SuperMini-style **[VERIFY pinout + row spacing]** | WiFi node, **2.4 GHz only**. Replaces the XIAO C5 |
| U3 | ESP32-H2 SuperMini, [nde3d](https://nde3d.co.za/esp-devices/3991-esp32-h2-supermini-development-board.html) R101.82 | 1 | 2x 1x8 female 2.54 mm **[VERIFY pinout + row spacing]** | BLE node (802.15.4 later). Has no WiFi. Replaces the XIAO C6. If H2 BLE gives trouble in Arduino, fall back to the ESP32-C3 SuperMini ([nde3d](https://nde3d.co.za/esp-devices/3413-esp32-c3-supermini-wifi-bluetooth-compatible-board-supermini-development-board-development-board-core-board-for-arduino.html) R91) |
| DISP1 | 2.8" SPI TFT, ILI9341, 320x240, 14-pin header, [nde3d](https://nde3d.co.za/displays/2409-28-inch-tft-lcd-colorful-screen-display-module.html) R468 (**only 1 in stock**) | 1 | 1x14 female 2.54 mm | Leave the touch pins unconnected. It has its own SD slot, which is unused (J_SD is used instead) |
| U4 | CC1101 433 MHz with spring antenna + IPEX, [nde3d](https://nde3d.co.za/rf-modules/2959-433mhz-cc1101-wireless-rf-transceiver-module.html) R114 | 1 | 1x8 2.54 mm **[VERIFY pin order; it varies by vendor]** | 3.3 V only. 433 MHz band chosen for SA |
| U5 | GY-NEO-7M GPS with ceramic patch antenna, [nde3d](https://nde3d.co.za/rf-modules/3191-gy-neo-7m-gps-active-ceramic-antenna-module.html) R136.48 | 1 | 1x4 2.54 mm **[VERIFY pin order]** | Pins: VCC, GND, TX, RX. Replaces the NEO-M8N/M10, which nde3d doesn't stock |
| J_SD | Micro TF/SD shield for D1 Mini (plain 3.3 V SPI), [nde3d](https://nde3d.co.za/modules/779-micro-tfsd-card-shield-for-d1-mini.html) R24 | 1 | wired to 1x6 2.54 mm **[VERIFY: uses the D1 Mini header's 3V3, GND and D5-D8 pins]** | Do NOT use nde3d's "SPI SD Card Module": it has a full-size slot and 5 V circuitry |
| PB1 | IP5310 charge + 5 V boost power-bank board, USB-C, 3.1 A out, [nde3d](https://nde3d.co.za/power-supplies/3267-5v-to-24v-3a-lithium-battery-charging-boosting-module.html) R62 (**only 4 in stock**) | 1 | wired to a 2-pin 5V/GND pad pair and a 2-pin BAT pad pair **[VERIFY pads]** | Replaces the PowerBoost 1000C. It has no EN or LBO pin. Protection against over-charge, over-discharge and shorts is built in. Backup: 5V 2A module ([nde3d](https://nde3d.co.za/power-supplies/3272-5v-2a-charge-and-discharge-boost-module-37v42v.html) R27) |
| BT1 | Sanyo 18650 3300 mAh Li-ion, [nde3d](https://nde3d.co.za/consumables/2201-18650-li-ion-battery-3000mah.html) R189.40 (forces road freight), plus a 1-cell holder with wires, [nde3d](https://nde3d.co.za/battery-holders/2436-18650-battery-holder-with-wires.html) R7 | 1 | holder on the bottom face, wired to PB1 BAT | Replaces the 1S LiPo pouch (none in stock). Alternative: 2200 mAh 18650 at R79.40, but its listing also says 1.5 Ah |
| SW_NAV | Five-way navigation button module (up/down/left/right/mid, SET/RST, COM), [nde3d](https://nde3d.co.za/buttons/1744-five-way-navigation-button-module.html) R21.21 | 1 | 1x7 female 2.54 mm **[VERIFY pin order]** | Replaces SW1-SW5. SET and RST are unused. COM goes to GND |

### 1.2 Board-level parts

| Ref | Part | Qty | Footprint | Source / notes |
|---|---|---|---|---|
| SW_PWR | Mini slide switch | 1 | THT **[VERIFY pitch]** | [nde3d](https://nde3d.co.za/switches/1738-mini-slide-switch-with-mounting-hole-pack-of-3.html) R10 for 3. In series with the PB1 5 V output, because PB1 has no EN pin |
| F1 | **DNP: bridge with wire or a 0 Ohm link.** Keep the radial 5 mm footprint | (1) | radial 5 mm THT | nde3d has no resettable fuse, and PB1 has output short protection. Fit a 1.1 A PTC later if you source one elsewhere |
| D1-D3 | 1N5819W Schottky | 3 | **SOD-323** (was DO-41) | [nde3d](https://nde3d.co.za/diodes/3391-1n5819w-smd-schottky-diode-sod123323523.html) R5 for 10. One per module 5 V input, to block USB back-feed |
| C1 | 470 uF 35 V electrolytic | 1 | radial 8 mm THT **[VERIFY diameter]** | [nde3d](https://nde3d.co.za/capacitors/3347-22uf-16v-electrolytic-capacitor-pack-of-5.html) R20 for 5 |
| C2-C4 | **220 uF 16 V** electrolytic (100 uF is out of stock) | 3 | radial 6.3 mm THT | [nde3d](https://nde3d.co.za/capacitors/1817) R6 for 5 |
| C5-C11, C13 | 100 nF 50 V ceramic | 8 | **THT, 5 mm pitch** (was 0805) | [nde3d](https://nde3d.co.za/capacitors/2832-100nf-50v-10-ceramic-cap-pack-of-5.html) R5.07 for 5; buy 2 packs |
| C12 | 10 uF 50 V ceramic | 1 | THT, 5 mm pitch | [nde3d](https://nde3d.co.za/capacitors/3634-100nf-50v-10-ceramic-cap-pack-of-5.html) R5.07 for 5. On GPS VCC |
| R1, R2 | 100 kOhm 1% 1/4 W metal film | 2 | **THT axial** (was 0805) | [nde3d](https://nde3d.co.za/resistors/503-resistor-thl-14w-1-pack-of-10.html) R5 for 10. The VBAT divider is now the **only** low-battery signal |
| R3-R7 | 10 kOhm | — | removed | The buttons moved to SW_NAV, which uses the internal pull-ups |
| R8 | 1 kOhm 1/4 W | 1 | THT axial | Same listing as R1 |
| LED1 | 3 mm green LED | 1 | 3 mm THT | [nde3d](https://nde3d.co.za/leds-bulbs/469-3mm-green-led-diffused-pack-of-5.html) R12 for 5 |
| JP1 | 3-pad solder jumper | 1 | | Backlight: pad A = always on (3V3), pad B = GPIO7 control. **Default: bridge A** |
| J_SPARE | 1x6 pin header | 1 | 2.54 mm | 3V3, GND, GPIO18, GPIO21, GPIO48, 5V |
| TP1-TP3 | Test points | 3 | 1 mm pad | 5V, 3V3, GND |
| H1-H4 | M3 mounting holes | 4 | 3.2 mm | 4 mm in from each corner. [M3 nylon standoff kit](https://nde3d.co.za/bolts-nuts/3354-sdafasdf.html) R98.78 |

### 1.3 Headers, extras, cost
- 2.54 mm female header: the [40-way strip](https://nde3d.co.za/plugs-sockets-connectors/1503-40-way-female-pin-header-single-row-254mm-01.html) is R7.50; buy **4**. The board needs about 116 pins: 1x22 x2, 1x8 x4, 1x14, 1x8, 1x7, 1x6 and 1x4.
- nde3d doesn't sell a suitable 2.4 GHz IPEX/U.FL antenna for U2 (the stick-on one is out of stock). It's optional; the onboard ceramic antenna works.
- You also need an enclosure and USB-C cables (one per module for flashing).
- **The core nde3d cart is about R1,630**, plus R118 for spares (C3 SuperMini and the 5V 2A module). Shipping is free over R2,000. The Sanyo 18650 forces road freight.

### 1.4 What changed from the original BOM, and the consequences
| Change | Consequence |
|---|---|
| XIAO C5 -> ESP32-C3 PRO Mini | **No 5 GHz capture**, but most dual-band APs also beacon on 2.4 GHz. The node footprint changes, and the firmware board target changes from `XIAO_ESP32C5` to generic ESP32C3. The UART and GPS pins need remapping **[VERIFY]** |
| XIAO C6 -> ESP32-H2 SuperMini | Keeps BLE and 802.15.4. This node doesn't need WiFi. First confirm that Arduino-ESP32 3.x BLE scanning compiles and runs on the H2; if not, fall back to the C3 SuperMini |
| PowerBoost 1000C -> IP5310 board | The 3.1 A output removes the ~1 A budget risk. It has **no EN pin**, so SW_PWR moves to the 5 V output. It has **no LBO pin**, so low battery comes from VBAT_SENSE (GPIO6), which the firmware must now read. Charge-while-running (pass-through) isn't documented, so bench-test plugging in USB-C while the deck runs. Expect a possible brief dropout |
| 1S LiPo -> 18650 + holder | The cell is 18 mm tall on the bottom face, which fits the ~25 mm depth budget. The IP5310 provides the cell protection |
| SW1-SW5 -> 5-way nav module | One 1x7 header replaces five switches |
| PTC fuse -> DNP | Relies on PB1's short-circuit protection |
| 0805 passives -> THT | Easier to hand-solder. The footprints change |
| NEO-M8N -> NEO-7M | Lower maximum update rate, which is fine for wardriving |

## 2. Power tree

```
BT1 (18650 in holder) --wires--> PB1.BAT (IP5310 board)
PB1 5V --> SW_PWR --> F1 (DNP, bridged) --> C1 470uF --> 5V_RAIL
5V_RAIL --> D1 --> C2 --> U2.5V   (ESP32-C3 PRO Mini, WiFi)
5V_RAIL --> D2 --> C3 --> U3.5V   (ESP32-H2 SuperMini, BLE)
5V_RAIL --> D3 --> C4 --> U1.5V   (S3 devkit)
5V_RAIL --> R8 --> LED1 --> GND
U1.3V3 --> 3V3_HUB  (powers DISP1, U4, U5, J_SD, J_SPARE)
GND common everywhere (one solid ground plane)
PB1.BAT --> R1 --> VBAT_SENSE --> R2 --> GND ; C13 across R2 ; VBAT_SENSE --> U1.GPIO6
```

3.3 V load on U1's onboard regulator (~800 mA LDO): display ~100 mA + GPS ~50 mA + CC1101 ~35 mA + SD burst ~100 mA + S3 itself ~150-350 mA. Peak is close to the LDO limit. If the S3 browns out under load, power the display/SD from a separate 3.3 V regulator — don't reduce anything else first.

5 V budget: WiFi node ~250-300 mA peak, BLE node ~150 mA, S3 ~300-350 mA including 3V3 loads, display ~100 mA. **~900 mA-1 A peak.** The IP5310 board is rated 3.1 A, so there is headroom; still measure it on the bench. The C3/H2 nodes draw somewhat less than the C5/C6 estimates.

## 3. Netlist

### 3.1 Hub U1 (ESP32-S3-DevKitC-1) — GPIOs assigned

Pins avoided on purpose: GPIO0, 3, 45, 46 (strapping), 19/20 (USB), 26-32 (flash/PSRAM), 33-37 (kept free of octal PSRAM).

| Net | U1 GPIO | Connects to |
|---|---|---|
| SPI_SCLK | 12 | DISP1.SCK, J_SD.SCK, U4.SCK |
| SPI_MOSI | 11 | DISP1.SDI(MOSI), J_SD.MOSI, U4.MOSI(SI) |
| SPI_MISO | 13 | J_SD.MISO, U4.MISO(SO) — **DISP1.SDO is NOT connected** (avoids contention) |
| TFT_CS | 10 | DISP1.CS |
| TFT_DC | 9 | DISP1.DC/RS |
| TFT_RST | 8 | DISP1.RESET |
| TFT_BL | 7 | JP1 pad B (backlight control) |
| SD_CS | 14 | J_SD.CS |
| CC_CS | 15 | U4.CSN |
| CC_GDO0 | 16 | U4.GDO0 |
| CC_GDO2 | 17 | U4.GDO2 |
| WIFI_LINK_RX | 4 | U2 NODE_TX |
| WIFI_LINK_TX | 5 | U2 NODE_RX |
| BLE_LINK_RX | 1 | U3 NODE_TX |
| BLE_LINK_TX | 2 | U3 NODE_RX |
| BTN_UP | 38 | SW_NAV.UP |
| BTN_DOWN | 39 | SW_NAV.DOWN |
| BTN_LEFT | 40 | SW_NAV.LEFT |
| BTN_RIGHT | 41 | SW_NAV.RIGHT |
| BTN_SEL | 42 | SW_NAV.MID |
| VBAT_SENSE | 6 | midpoint of R1/R2. **The only low-battery signal now; firmware must implement it** |
| SPARE | 18, 21, 48 | J_SPARE |
| (unused) | 47 | was PB1.LBO; the IP5310 board has no LBO pin |
| 5V | 5V pin | D3 cathode (via C4) |
| 3V3 | 3V3 pin (either) | 3V3_HUB net |
| GND | GND pins | GND |

Header positions on the DevKitC-1 (left row J1: 3V3, 3V3, RST, 4, 5, 6, 7, 15, 16, 17, 18, 8, 3, 46, 9, 10, 11, 12, 13, 14, 5V, GND; right row J3: GND, TX, RX, 1, 2, 42, 41, 40, 39, 38, 37, 36, 35, 0, 45, 48, 47, 21, 20, 19, GND, GND) **[VERIFY against the Espressif DevKitC-1 schematic before drawing the footprint]**.

### 3.2 Nodes U2 (ESP32-C3 PRO Mini) and U3 (ESP32-H2 SuperMini): identical logical wiring

The pin labels are logical. **Map each one to a real GPIO from the board's pinout before drawing the footprint [VERIFY].** Avoid the strapping pins (C3: GPIO2, 8, 9; H2: GPIO8, 9, 25). On the C3, GPIO20/21 are the default UART0 RX/TX. The v2 firmware still uses the XIAO `D`-labels and must be updated to match.

| Net | Node pin | Connects to |
|---|---|---|
| LINK_TX | NODE_TX (UART to hub) | Hub RX (U2 -> U1.GPIO4, U3 -> U1.GPIO1) |
| LINK_RX | NODE_RX | Hub TX (U2 <- U1.GPIO5, U3 <- U1.GPIO2) |
| GPS_RX | NODE_GPS_RX (second UART RX) | U5.TX (the same GPS TX line goes to both nodes) |
| 5V | 5V | D1 (U2) / D2 (U3) cathode, via C2/C3 |
| GND | GND | GND |
| (unused) | all other pins, 3V3 | leave unconnected |

Firmware board targets: generic `ESP32C3 Dev Module` (USB CDC on boot enabled) and `ESP32H2 Dev Module`.

### 3.3 GPS U5

| U5 pin | Connects to |
|---|---|
| VCC | 3V3_HUB (through C12 10 uF + C10 100 nF to GND) — check your module accepts 3.3 V |
| GND | GND |
| TX | U2 NODE_GPS_RX **and** U3 NODE_GPS_RX |
| RX | not connected (leave a test pad; module is configured over USB-TTL beforehand) |

### 3.4 Display DISP1 (MSP2807-type, 14 pins) **[VERIFY pin order on your module]**

| Pin | Connects to |
|---|---|
| VCC | 3V3_HUB |
| GND | GND |
| CS | TFT_CS (GPIO10) |
| RESET | TFT_RST (GPIO8) |
| DC/RS | TFT_DC (GPIO9) |
| SDI (MOSI) | SPI_MOSI (GPIO11) |
| SCK | SPI_SCLK (GPIO12) |
| LED (backlight) | JP1 common pad (A -> 3V3_HUB, B -> TFT_BL GPIO7) |
| SDO (MISO) | **not connected** |
| T_CLK, T_CS, T_DIN, T_DO, T_IRQ | not connected |

### 3.5 CC1101 U4 **[VERIFY pin order]**

| Signal | Connects to |
|---|---|
| VCC | 3V3_HUB only (max 3.6 V — never 5 V) |
| GND | GND |
| SCK | SPI_SCLK |
| MOSI (SI) | SPI_MOSI |
| MISO (SO) | SPI_MISO |
| CSN | CC_CS (GPIO15) |
| GDO0 | CC_GDO0 (GPIO16) |
| GDO2 | CC_GDO2 (GPIO17) |

### 3.6 microSD J_SD

| Signal | Connects to |
|---|---|
| 3V3 | 3V3_HUB |
| GND | GND |
| CS | SD_CS (GPIO14) |
| MOSI | SPI_MOSI |
| MISO | SPI_MISO |
| SCK | SPI_SCLK |

### 3.7 Power stage PB1 (IP5310 power-bank board) **[VERIFY pads]**

| PB1 pad | Connects to |
|---|---|
| BAT+ / BAT- | BT1 18650 holder wires; BAT+ also to R1 (VBAT sense) |
| 5V OUT (+) | SW_PWR -> F1 (bridged) -> 5V_RAIL |
| GND (-) | GND |
| USB-C | charging input, reachable from the enclosure edge |
| USB-A | unused |

The on-board button wakes the IP5310 after a battery insert. Power-bank chips turn their output off below roughly 50-100 mA of load; the deck draws more than that, but check it doesn't shut down when idle.

### 3.8 Passives

| Ref | Between |
|---|---|
| SW_PWR | PB1 5V OUT and F1 |
| F1 | SW_PWR and 5V_RAIL (DNP, bridged) |
| C1 | 5V_RAIL to GND |
| D1, D2, D3 | anode 5V_RAIL, cathode to U2.5V / U3.5V / U1.5V |
| C2, C3, C4 | each module's 5V pin (after its diode) to GND |
| C5-C11 | 3V3/VCC of U1, U2, U3, DISP1, U4, U5, J_SD to GND, placed right at each pin |
| R1, R2 | PB1.BAT+ -> R1 -> VBAT_SENSE -> R2 -> GND |
| C13 | VBAT_SENSE to GND |
| R8, LED1 | 5V_RAIL -> R8 -> LED1 -> GND |
| SW_NAV | UP/DOWN/LEFT/RIGHT/MID to GPIO38-42 (see 3.1), COM to GND, SET/RST unconnected |
| J_SPARE | pin1 3V3_HUB, pin2 GND, pin3 GPIO18, pin4 GPIO21, pin5 GPIO48, pin6 5V_RAIL |

## 4. Layout rules (from the RF and power findings)

1. **Two layers, one solid ground plane** on the bottom layer. Do not split it.
2. **Keep-outs:** no copper, traces or components under the antenna end of U2/U3 (over each node's onboard antenna) or under the GPS patch antenna and its module.
3. **RF separation:** U2 and U3 at opposite short edges, ~10 cm apart. Both are receive-only, so this is a precaution.
4. **Placement:** hub U1 + DISP1 on the top face; U2, U3, U4, PB1 and the battery on the bottom face. GPS at the top edge with sky view. CC1101 antenna at a board edge, away from U2/U3 antennas.
5. **Power traces:** 1 mm minimum on 5V_RAIL, 1.5 mm from PB1 to C1. Put every bulk cap (C1-C4) close to the pin it feeds.
6. **USB-C access:** each module's USB-C must be reachable from the enclosure edge for flashing.
7. **SPI:** keep SCLK/MOSI short and away from the GPS. If the display SPI runs above ~40 MHz, add 33 Ohm series resistors on SCLK/MOSI (footprints only, DNP by default).

## 5. Open items before ordering boards
1. Footprint dimensions and pad order for every **[VERIFY]** item — do this from the datasheet or by measuring the physical part.
2. Measure real peak 5 V draw on the bench; switch to a 2 A boost module if > 900 mA.
3. Confirm the ESP32-H2 BLE scan works in Arduino-ESP32 3.x; fall back to a C3 SuperMini if not.
4. CC1101 band: 433 MHz (decided 2026-09-25 for SA).
5. Bench-test the IP5310: charge while running (dropout?), and idle auto-shutdown.
6. Decide whether the display backlight needs dimming; if so, replace JP1 with an AO3401 P-channel switch (not included here to keep the first spin simple).

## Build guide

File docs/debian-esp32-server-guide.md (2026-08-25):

# Debian Server as a Remote Arduino/ESP32 Flashing Station

Host: `debianhomelab` (Debian 12 bookworm) at `192.168.3.17`, user `lincalibur`.
Set up because local USB passthrough to Arduino IDE was unreliable — the server now compiles and flashes over SSH using `arduino-cli`.

## What's already set up on the server

- SSH key auth from this machine (`~/.ssh/id_ed25519`) — no password needed
- `lincalibur` is in the `dialout` group (USB serial access) and `sudo` (passwordless)
- `arduino-cli` installed at `/usr/local/bin/arduino-cli`
- Board cores installed: `arduino:avr` (Uno/Nano/Mega) and `esp32:esp32` (all ESP32 variants)

## 1. Connect

```bash
ssh lincalibur@192.168.3.17
```

No password prompt — the key was installed in `~/.ssh/authorized_keys` on the server.

## 2. Plug in the ESP32

Plug the ESP32 into a USB port **on the Debian server** (not your local machine). Then check it's detected:

```bash
ssh lincalibur@192.168.3.17 "arduino-cli board list"
```

Look for a line like:
```
/dev/ttyUSB0   serial   Espressif ESP32 ...   esp32:esp32:esp32
```

Most ESP32 dev boards use a CP210x or CH340 USB-serial chip and show up as `/dev/ttyUSB0`. Genuine Arduino Uno/Nano/Mega boards usually show up as `/dev/ttyACM0` — and so does the **ESP32-C3**, which has a native USB-JTAG/CDC controller instead of an external USB-serial chip (identifies itself as "USB JTAG/serial debug unit", Espressif vendor ID `303a`).

If nothing shows up: unplug/replug and re-run the command, or check `dmesg | tail -20` on the server for USB enumeration errors.

## 3. Get your sketch onto the server

Arduino sketches need to live in a folder with the **same name as the `.ino` file** (this is an arduino-cli/Arduino IDE requirement).

Option A — write/edit directly on the server:
```bash
ssh lincalibur@192.168.3.17
mkdir -p ~/sketches/MyProject
nano ~/sketches/MyProject/MyProject.ino
```

Option B — write locally and copy over (recommended if you want to keep sketches in this repo):
```bash
scp -r ./my-sketch-folder lincalibur@192.168.3.17:~/sketches/
```
or keep it synced with `rsync`:
```bash
rsync -av --delete ./esp32-code/ lincalibur@192.168.3.17:~/sketches/MyProject/
```

## 4. Compile

```bash
ssh lincalibur@192.168.3.17 "arduino-cli compile --fqbn esp32:esp32:esp32 ~/sketches/MyProject"
```

Common ESP32 board FQBNs (find more with `arduino-cli board listall | grep -i esp32`):

| Board | FQBN |
|---|---|
| Generic ESP32 Dev Module | `esp32:esp32:esp32` |
| ESP32-S3 Dev Module | `esp32:esp32:esp32s3` |
| ESP32-C3 Dev Module | `esp32:esp32:esp32c3:CDCOnBoot=cdc` (see [USB CDC gotcha](#esp32-c3-usb-cdc-gotcha) below) |
| ESP32-WROOM-32 | `esp32:esp32:esp32` |

## 5. Upload (flash)

```bash
ssh lincalibur@192.168.3.17 "arduino-cli upload -p /dev/ttyUSB0 --fqbn esp32:esp32:esp32 ~/sketches/MyProject"
```

Adjust `-p /dev/ttyUSB0` to whatever `arduino-cli board list` showed in step 2.

Compile and upload in one line:
```bash
ssh lincalibur@192.168.3.17 "arduino-cli compile --fqbn esp32:esp32:esp32 ~/sketches/MyProject && arduino-cli upload -p /dev/ttyUSB0 --fqbn esp32:esp32:esp32 ~/sketches/MyProject"
```

### ESP32-C3 USB CDC gotcha

The ESP32-C3 has a native USB-JTAG/CDC controller built in (no separate CP210x/CH340 chip). By default, arduino-cli's `esp32:esp32:esp32c3` FQBN builds with **USB CDC On Boot disabled**, which routes `Serial` output to the physical UART0 pins instead of the USB port. Result: the sketch flashes and runs fine, but `arduino-cli monitor` on `/dev/ttyACM0` shows nothing at all — looks like a dead board when it isn't.

Fix: always compile and upload ESP32-C3 sketches with the `CDCOnBoot=cdc` config option appended to the FQBN:

```bash
arduino-cli compile --fqbn 'esp32:esp32:esp32c3:CDCOnBoot=cdc' ~/sketches/MyProject
arduino-cli upload -p /dev/ttyACM0 --fqbn 'esp32:esp32:esp32c3:CDCOnBoot=cdc' ~/sketches/MyProject
```

(Quote the FQBN — the colon-separated config suffix needs to survive shell parsing over SSH.)

## 6. Monitor serial output

```bash
ssh lincalibur@192.168.3.17 "arduino-cli monitor -p /dev/ttyUSB0 -c baudrate=115200"
```
Exit with `Ctrl+C`.

## Installing libraries

```bash
ssh lincalibur@192.168.3.17 "arduino-cli lib search <name>"
ssh lincalibur@192.168.3.17 "arduino-cli lib install \"<Library Name>\""
```

## Arduino (AVR) boards instead of ESP32

Same flow, different FQBN and port:
```bash
arduino-cli compile --fqbn arduino:avr:uno ~/sketches/MyProject
arduino-cli upload -p /dev/ttyACM0 --fqbn arduino:avr:uno ~/sketches/MyProject
```

## One-liner shortcut

Add this to your local `~/.bashrc` / `~/.zshrc` for convenience:
```bash
flash-esp32() {
  local sketch="$1"
  local port="${2:-/dev/ttyUSB0}"
  ssh lincalibur@192.168.3.17 "arduino-cli compile --fqbn esp32:esp32:esp32 ~/sketches/$sketch && arduino-cli upload -p $port --fqbn esp32:esp32:esp32 ~/sketches/$sketch"
}
```
Usage: `flash-esp32 MyProject`

## Troubleshooting

- **Permission denied on serial port**: shouldn't happen (`lincalibur` is in `dialout`), but if it does: `ssh lincalibur@192.168.3.17 "groups"` should list `dialout`. Logging out/in again fixes stale group membership after being added.
- **Board not detected**: check `dmesg | tail` on the server after plugging in. If a driver conflict appears (e.g. `brltty` grabbing the device — not currently installed on this server, but can get installed as a dependency later), remove it: `sudo apt remove brltty`.
- **Wrong FQBN**: run `arduino-cli board listall | grep -i <board name>` to find the exact string.
- **ESP32-C3 flashes fine but no serial output**: you forgot `CDCOnBoot=cdc` — see [USB CDC gotcha](#esp32-c3-usb-cdc-gotcha) above.
- **Sudo/root access**: `lincalibur` has passwordless sudo (`/etc/sudoers.d/lincalibur`) for installing new libraries/tools system-wide if ever needed.

## Optional next step: remote editing with a real editor

Instead of `nano` over SSH, you can use **VS Code Remote-SSH** (`Remote-SSH: Connect to Host...` → `lincalibur@192.168.3.17`) to edit sketches with full syntax highlighting directly on the server, then run the compile/upload commands above in the integrated terminal. Ask if you'd like this set up (VS Code + PlatformIO extension is also an option for a more IDE-like ESP32 workflow).

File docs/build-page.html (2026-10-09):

# War-rig-phantom: clamshell build Budget v1

A portable, passive counter-surveillance deck in a 22 × 22 cm clamshell case. It listens to WiFi, BLE and 433 MHz, tags sightings with GPS, and flags devices that keep following you. Each scan module has its own screen in the lid; an ESP32-S3 is the hub. A Raspberry Pi 5 replaces the hub later.

- Case 220 × 220 × 70 mm
- Hub ESP32-S3, wired UART links
- Power 2S2P 18650, 5 V rail
- Cart R1,390 at nde3d
- Receive only: no deauth, injection or jamming

## Boards

Every board has one fixed name. It is used in the docs and firmware, and should be on a label stuck to the board.

Name | Board | Job | Where
HUB | ESP32-S3-DevKitC-1 N16R8 | Collects node reports, logs to microSD, runs the CC1101, drives alerts | Base, under deck
READOUT | Arduino UNO R3 + 3.5" TFT shield | Hub display. A dumb terminal that draws rows sent by the HUB | Lid, middle-left
BLE-SCAN | ESP32-1732S019 (ESP32 + built-in 1.9" screen) | BLE tracker detection on its own screen | Lid, top-middle
WIFI-NODE | ESP32-C3 (first) | Headless WiFi promiscuous scanner | Base, under deck
STATUS | ESP32-C3 (second) + 128×64 OLED | Status and counters. Standalone in v1 | Lid, top-left

## Layout

Lid and base seen from inside, plus a side section of the closed case. Dimensions are planning figures; measure the case before cutting.

Top-down layout of the lid and base and a side section of the closed case. Lid: STATUS OLED, BLE-SCAN 1.9 inch, READOUT 3.5 inch, alerts and SD strip, blank plate with GPS. Base: power zone, six sec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

### Depth rule

Each half is about 35 mm deep. With the deck raised for the cell holder, switch caps plus screen protrusion must stay under about 16 mm combined or the lid won't close.

### Faceplate

3 mm acrylic or a 3D print. Not aluminium: the ESP32 antennas sit behind the plate and metal would shield them.

### Measure first

The BLE-SCAN board outline against its 55 × 40 mm zone, and the READOUT stack height (about 25–30 mm against a 23 mm budget).

## Parts

Tick parts off as you collect them; ticks are saved in this browser. Prices are as nde3d.co.za listed them on 2026-10-09.

0 of 0 items ticked Copy shopping list Clear ticks

| Part | Qty | Price | Role

## Power

One 2S2P pack feeds a single 5 V buck. Every module has its own section switch. Load is about 1–1.5 A at 5 V; expect roughly 3–4 hours and measure it.

Before connecting anything: check the 4-cell holder with a multimeter and rewire it to 2S2P if it arrives as 4S (about 15 V). Set the charger to 8.4 V and the buck to about 5.1 V with no load. Never connect a single-cell USB charge/boost board to this pack.

12 V adapter -> DC jack -> XL4015 CC/CV (8.4 V, ~1 A) -+
                                                       v
18650 2S2P pack <-> 2S 20 A BMS -> fuse 8 A -> master switch -> 5 A buck (5.1 V) -> section switches
        |
        +-> capacity indicator (2S)

Switch | Powers
Master | Everything, after the fuse
1 | HUB: ESP32-S3 + microSD + CC1101 + GPS
2 | READOUT: UNO + 3.5" TFT (through the UNO's 5 V pin)
3 | BLE-SCAN
4 | STATUS: C3 + OLED
5 | WIFI-NODE
6 | Aux (spare)

## Wiring

All links are wired 3.3 V UART and the radios only receive. HUB pins for SPI, CC1101 and the node links come from the earlier netlist. Pins marked proposed are not in the firmware yet.

GPS (NEO-7M) TX --+--> WIFI-NODE (ESP32-C3) ---UART--+
                  +--> BLE-SCAN (ESP32) -------UART--+--> HUB (ESP32-S3) --row stream, one-way UART--> READOUT (UNO + 3.5")
                                                              |
                                                              +-- SPI: microSD shield, CC1101 433 MHz
                                                              +-- LED + piezo alerts

### HUB (ESP32-S3)

GPIO | Net | Goes to
12 | SPI_SCLK | SD, CC1101
11 | SPI_MOSI | SD, CC1101
13 | SPI_MISO | SD, CC1101
14 | SD_CS | microSD shield
15 | CC_CS | CC1101 CSN
16 | CC_GDO0 | CC1101
17 | CC_GDO2 | CC1101
4 | WIFI_LINK_RX | WIFI-NODE TX
5 | WIFI_LINK_TX | WIFI-NODE RX
1 | BLE_LINK_RX | BLE-SCAN GPIO17
2 | BLE_LINK_TX | BLE-SCAN GPIO16
9 | READOUT_TX (proposed) | UNO D0
18 | BUZZER (proposed) | Piezo
21 | ALERT_LED (proposed) | LED + resistor

GPIO35–37 stay unconnected (octal PSRAM). The CC1101, SD and GPS are powered from the HUB's 3V3 pin; the CC1101 must never see 5 V.

### Nodes and display

Board | Pin | Goes to
BLE-SCAN | GPIO17 TX | HUB GPIO1
BLE-SCAN | GPIO16 RX | HUB GPIO2
BLE-SCAN | GPIO22 GPS RX (proposed) | GPS TX
WIFI-NODE | GPIO7 TX (proposed) | HUB GPIO4
WIFI-NODE | GPIO6 RX (proposed) | HUB GPIO5
WIFI-NODE | GPIO20 GPS RX (proposed) | GPS TX
READOUT | D0 RX | HUB GPIO9

- Put about 1 kΩ in series on each UART line between separately switched boards.
- The GPS TX line fans out to both nodes, so each node stamps its own sightings. The HUB takes position and time from their reports.
- The S3 has three UARTs: one per node link and one for the READOUT stream.
- Unplug the READOUT D0 wire while flashing the UNO.
- Common ground between every board.

## Build order

1. Measure the case interior and make cardboard templates of the faceplate and deck. Test-fit with the case closed.
2. Build the power system on the bench: holder wiring, BMS, fuse, charger at 8.4 V, buck at 5.1 V, switches.
3. Bring up the HUB on the bench: microSD, then GPS, then one node at a time, then the READOUT link.
4. Cut the faceplate and deck plate. Cut the DC jack and battery meter openings in the front pockets.
5. Mount the screens and boards. Route the hinge bundle in mesh sleeve with a slack loop.
6. Close test: confirm nothing touches when the lid shuts.
7. Walk test, log check and a runtime measurement.

## Pi phase Later

The case and power system are sized so a Raspberry Pi 5 can take over as hub without a rebuild. nde3d stocks none of the main parts, so these come from another supplier.

### What gets added

- Raspberry Pi 5, microSD and a low-profile cooler
- 5" display in the blank lid slot, DSI touch preferred
- Powered USB hub and an RTL-SDR with SMA jacks
- A second 5 V buck for the lid modules
- USB-A, USB-C and microSD panel extensions

### What changes

- The Pi gets the 5 A buck to itself.
- Boards link to the Pi over USB serial, so section switches move to each cable's VBUS line.
- A shutdown button goes on the Pi's power header; cutting power corrupts its SD card.
- READOUT becomes the main scan view instead of the hub display.

Full detail is in the repository: hardware-layout.md (https://github.com/Lincalibur/War-rig-phantom/blob/main/docs/hardware-layout.md) and OVERVIEW.md (https://github.com/Lincalibur/War-rig-phantom/blob/main/docs/OVERVIEW.md). The earlier single-PCB design is shelved; its interactive page is kept at pcb-v2.html.

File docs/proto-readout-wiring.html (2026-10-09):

# Big-screen readout — wiring

A bench prototype built from spare parts: an ESP32-C3 scans WiFi + BLE and streams "draw this row" commands over one wire to an Arduino UNO, which paints a 3.5" TFT shield and logs to its microSD. This page shows exactly what connects where. Firmware lives in v2/proto_readout_c3/ and v2/proto_readout_uno/.

- Link one-way UART, C3 → UNO
- Just 2 signal wires (data + ground)
- Power 2-port USB power bank
- Baud 19200 (Option A) · 9600 (Option B)

## How it all connects

The C3 and UNO are powered separately from the two ports of one power bank, so the only wires between the boards are the data line and a common ground. The TFT shield plugs straight onto the UNO.

data (C3 TX → UNO RX) common ground 5 V power (from bank)

## The link — just two wires

Because each board draws power from its own port on the bank, nothing but the data line and a shared ground crosses between them. The C3's 3.3 V TX drives the UNO's 5 V RX fine — no level shifter needed this direction.

Signal connections
From (ESP32-C3) | To (Arduino UNO) | Purpose
GPIO21 (Serial1 TX) | D0 (RX) | Row-draw + log commands
GND | GND (ICSP pin 6) | Common ground — required

A 2-port power bank already shares ground internally, so the boards' grounds are tied through it. The dedicated GND wire is belt-and-suspenders for a clean signal — keep it.

## Two ways to reach the UNO's RX

The TFT shield covers every UNO header pin. You need access to a receive pin. Pick one approach.

Recommended · keeps SD

### Option A — free up D0

The shield's D0/D1 pins are dead (connected to nothing — they only use D2–D9, A0–A4, D10–D13). So there's no trace to cut; just get the dead D0 pin out of the UNO's socket.

1. Find D0 — the two pins nearest the USB connector are D0 (RX) and D1 (TX). You only touch D0.
2. Bend the shield's D0 male pin outward (away from the USB shell), or snip it flush. It's dead, so this is harmless.
3. Re-seat the shield. The UNO's D0 socket is now free.
4. Plug C3 GPIO21 into D0, and C3 GND into ICSP pin 6.

Keeps: hardware Serial (most reliable), microSD logging, 19200 baud. No code change.

No shield changes · drops SD

### Option B — use ICSP (D12)

The ICSP data pins are just D11/D12/D13 — the same bus the microSD uses. You can borrow MISO (D12) as a SoftwareSerial RX only if you give up the SD card.

1. Plug C3 GPIO21 into ICSP pin 1 (MISO / D12).
2. Plug C3 GND into ICSP pin 6 (GND).
3. Firmware changes: UNO uses SoftwareSerial on D12, parks the SD (drive D10 HIGH, never call SD.begin); both boards drop to 9600 baud.

Trade-off: no SD logging (display only), and SoftwareSerial is less tolerant than the hardware UART while the TFT is drawing. Ask and I'll hand you the modified sketches.

### ICSP header pinout (2×3 block)

Looking at the 6-pin block. Pin 1 is usually marked with a dot or a square pad.

Pin | Signal | Same as | Use here
1 | MISO | D12 | Data line (Option B only)
2 | VCC | 5V | — (power comes from the bank)
3 | SCK | D13 | — (SD bus)
4 | MOSI | D11 | — (SD bus)
5 | RESET | — | — do not use
6 | GND | GND | Common ground (both options)

Why ICSP can't give hardware serial: the ATmega's only UART RX is D0, and it isn't brought out to the ICSP header. ICSP is SPI + power + reset only.

## Power

Run both boards from the 2-port USB power bank for now — one port to the UNO's USB jack, one to the C3's USB.

Port | Feeds | Draw
1 | UNO + 3.5" TFT (backlight ~100–150 mA) | ~200 mA
2 | ESP32-C3 (WiFi/BLE bursts) | ~100 mA avg, 300 mA peak

Solar later, not now. A bare mini panel can't drive the backlight directly. To add solar you need a battery buffer + charger: a 5–6 V ≥2 W panel → CN3065/TP4056-solar charger (or an IP5310 board) → 18650 → 5 V out → both boards. Solar then trickle-charges while the battery does the work.

## Flashing & libraries

### ESP32-C3

Board: ESP32C3 Dev Module, USB CDC On Boot: Enabled. Flash over the C3's own USB. BLE + WiFi come with the core.

### Arduino UNO

Libraries: MCUFRIEND_kbv + Adafruit GFX Library (SD + SPI are built in). microSD CS = D10 on most shields — verify on yours.

Before uploading to the UNO: unplug the C3 → D0 wire. D0 is the USB serial RX; leaving the C3 driving it makes the upload fail. Reconnect it after flashing.

CyberDeck v2 · bench prototype wiring reference. See v2/proto_readout_c3/, v2/proto_readout_uno/, and docs/OVERVIEW.md for the full project.

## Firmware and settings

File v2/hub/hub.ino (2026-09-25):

// CyberDeck v2 — hub (ESP32-S3 + 2.8" ILI9341 + microSD + 5 buttons).
//
// Receives observations from the WiFi node and BLE node over two wired UARTs, keeps de-duplicated
// tables of what is around, shows it on the screen, and logs every geotagged sighting to the SD
// card in WiGLE CSV format (upload-ready) — access points and BLE devices to one file, client
// devices to a second.
//
// Board: ESP32S3 Dev Module — "USB CDC On Boot: Enabled", PSRAM: "OPI PSRAM" (N16R8 board; GPIO33-37 are left unused for it).
// Libraries: Adafruit GFX Library, Adafruit ILI9341 (SD, SPI come with the ESP32 core).
//
// Buttons: LEFT/RIGHT = page, UP/DOWN = scroll, SELECT = change sort.
// Pages:   NETWORKS, BLE, CLIENTS, STATUS.
//
// NOT YET FLASHED. Pin numbers are from docs/PCB-BOM-AND-NETLIST.md — VERIFY against your devkit.

#include <SPI.h>
#include <SD.h>
#include <Adafruit_GFX.h>
#include <Adafruit_ILI9341.h>
#include <time.h>
#include "../shared/deck_link.h"

// ---------------------------------------------------------------------------------------
// Pins
// ---------------------------------------------------------------------------------------
static const int PIN_SCLK = 12, PIN_MOSI = 11, PIN_MISO = 13;
static const int PIN_TFT_CS = 10, PIN_TFT_DC = 9, PIN_TFT_RST = 8, PIN_TFT_BL = 7;
static const int PIN_SD_CS = 14;
static const int PIN_CC1101_CS = 15;   // reserved; held high so it doesn't fight the shared bus
static const int PIN_WIFI_RX = 4, PIN_WIFI_TX = 5;   // UART1 <-> WiFi node
static const int PIN_BLE_RX  = 1, PIN_BLE_TX  = 2;   // UART2 <-> BLE node
static const int PIN_BTN_UP = 38, PIN_BTN_DOWN = 39, PIN_BTN_LEFT = 40, PIN_BTN_RIGHT = 41, PIN_BTN_SEL = 42;
static const int PIN_BAT_LOW = 47;     // PowerBoost LBO, active low

// ---------------------------------------------------------------------------------------
// Types (kept above every function: Arduino auto-generates prototypes, and structs used as
// parameters must already be defined where they are inserted)
// ---------------------------------------------------------------------------------------
static const int WIFI_MAX = 600, CLIENT_MAX = 400, BLE_MAX = 400;

struct WifiRec   { bool used; uint8_t mac[6]; int8_t rssi; uint8_t ch, enc, flags; char ssid[33]; uint32_t lastMs; uint16_t hits; };
struct ClientRec { bool used; uint8_t mac[6], ap[6]; int8_t rssi; uint8_t ch, flags; char probe[33]; uint32_t lastMs; };
struct BleRec    { bool used; uint8_t mac[6]; int8_t rssi; uint8_t flags; uint16_t mfg; char name[21]; uint32_t lastMs; uint16_t hits; };

static WifiRec   wifiTab[WIFI_MAX];
static ClientRec clientTab[CLIENT_MAX];
static BleRec    bleTab[BLE_MAX];
static int wifiN = 0, clientN = 0, bleN = 0;

struct Link {
  HardwareSerial* port;
  deck_link_parser_t parser;
  bool     seen;
  uint32_t lastHelloMs;
  uint8_t  kind, fw;
  uint32_t nodeFrames, nodeDropped, nodeUptime;
  uint32_t framesWindow, lastRateMs;
  uint16_t fps;              // link frames/sec, for the status page
  deck_stats_t stats;
  bool     haveStats;
};

// ---------------------------------------------------------------------------------------
// Display
// ---------------------------------------------------------------------------------------
static SPIClass hubSpi(FSPI);
static Adafruit_ILI9341 tft(&hubSpi, PIN_TFT_DC, PIN_TFT_CS, PIN_TFT_RST);

static const uint16_t C_BG = 0x0000, C_FG = 0xFFFF, C_GRAY = 0x8410, C_GREEN = 0x07E0, C_RED = 0xF800,
                      C_YELLOW = 0xFFE0, C_CYAN = 0x07FF, C_ORANGE = 0xFD20, C_HEAD = 0x0010;
static const int ROW_H = 10, COLS = 53, ROWS = 24, LIST_TOP = 3, LIST_ROWS = 20;

static char     rowCache[ROWS][COLS + 1];
static uint16_t rowFg[ROWS], rowBg[ROWS];

static void invalidateRows() {
  for (int r = 0; r < ROWS; r++) { rowCache[r][0] = 1; rowCache[r][1] = 0; }  // impossible content
}

// Redraws a text row only if it changed — keeps the ILI9341 from flickering.
static void drawRow(int row, const char* text, uint16_t fg = C_FG, uint16_t bg = C_BG) {
  char buf[COLS + 1];
  snprintf(buf, sizeof(buf), "%-*.*s", COLS, COLS, text);
  if (strcmp(buf, rowCache[row]) == 0 && rowFg[row] == fg && rowBg[row] == bg) return;
  strcpy(rowCache[row], buf);
  rowFg[row] = fg; rowBg[row] = bg;
  tft.setCursor(0, row * ROW_H + 1);
  tft.setTextColor(fg, bg);
  tft.print(buf);
}

// ---------------------------------------------------------------------------------------
// Data model
// ---------------------------------------------------------------------------------------
static Link wifiLink, bleLink;

static deck_geo_t lastGeo;
static uint32_t   lastGeoMs = 0;
static bool       lowBattery = false;

static uint16_t chanSmooth[13];

// ---------------------------------------------------------------------------------------
// SD logging (WiGLE CSV 1.4)
// ---------------------------------------------------------------------------------------
static bool sdOk = false;
static File wigleFile, clientFile;
static char wigleName[40], clientName[40];
static uint32_t wigleRows = 0, clientRows = 0, noFixRows = 0, lastFlushMs = 0;

static size_t appendCsv(char* dst, size_t cap, size_t pos, const char* s, size_t n) {
  bool quote = memchr(s, ',', n) || memchr(s, '"', n);
  if (quote && pos + 1 < cap) dst[pos++] = '"';
  for (size_t i = 0; i < n && pos + 2 < cap; i++) {
    char c = s[i];
    if ((uint8_t)c < 0x20) continue;        // strip control characters
    if (c == '"') dst[pos++] = '"';
    dst[pos++] = c;
  }
  if (quote && pos + 1 < cap) dst[pos++] = '"';
  dst[pos] = '\0';
  return pos;
}

static void fmtMac(char* out, const uint8_t* m) {
  snprintf(out, 18, "%02x:%02x:%02x:%02x:%02x:%02x", m[0], m[1], m[2], m[3], m[4], m[5]);
}

static void fmtTime(char* out, size_t cap, uint32_t utc) {
  time_t t = (time_t)utc;
  struct tm tmv;
  gmtime_r(&t, &tmv);
  strftime(out, cap, "%Y-%m-%d %H:%M:%S", &tmv);
}

static const char* wigleAuth(uint8_t enc) {
  switch (enc) {
    case DECK_ENC_OPEN:      return "[ESS]";
    case DECK_ENC_WEP:       return "[WEP][ESS]";
    case DECK_ENC_WPA:       return "[WPA-PSK-TKIP][ESS]";
    case DECK_ENC_WPA2:      return "[WPA2-PSK-CCMP][ESS]";
    case DECK_ENC_WPA3:      return "[WPA3-SAE-CCMP][ESS]";
    case DECK_ENC_WPA2_WPA3: return "[WPA2-PSK-CCMP][WPA3-SAE-CCMP][ESS]";
    case DECK_ENC_WPA2_ENT:  return "[WPA2-EAP-CCMP][ESS]";
    default:                 return "[ESS]";
  }
}

static const char* encName(uint8_t enc) {
  switch (enc) {
    case DECK_ENC_OPEN: return "OPEN";
    case DECK_ENC_WEP:  return "WEP";
    case DECK_ENC_WPA:  return "WPA";
    case DECK_ENC_WPA2: return "WPA2";
    case DECK_ENC_WPA3: return "WPA3";
    case DECK_ENC_WPA2_WPA3: return "WPA23";
    case DECK_ENC_WPA2_ENT:  return "ENT";
    default: return "?";
  }
}

static void openLogs() {
  sdOk = SD.begin(PIN_SD_CS, hubSpi, 20000000);
  if (!sdOk) return;
  SD.mkdir("/wardrive");
  int idx = 1;
  for (; idx < 10000; idx++) {
    snprintf(wigleName, sizeof(wigleName), "/wardrive/wigle_%04d.csv", idx);
    if (!SD.exists(wigleName)) break;
  }
  snprintf(clientName, sizeof(clientName), "/wardrive/clients_%04d.csv", idx);
  wigleFile = SD.open(wigleName, FILE_WRITE);
  clientFile = SD.open(clientName, FILE_WRITE);
  if (!wigleFile || !clientFile) { sdOk = false; return; }
  wigleFile.println("WigleWifi-1.4,appRelease=CyberDeck2,model=CyberDeck,release=2.0,device=CyberDeck,display=ILI9341,board=ESP32-S3,brand=DIY");
  wigleFile.println("MAC,SSID,AuthMode,FirstSeen,Channel,RSSI,CurrentLatitude,CurrentLongitude,AltitudeMeters,AccuracyMeters,Type");
  clientFile.println("MAC,APMAC,ProbedSSID,Time,Channel,RSSI,Latitude,Longitude,Flags");
}

static void closeLogs() {
  if (!sdOk) return;
  wigleFile.flush(); wigleFile.close();
  clientFile.flush(); clientFile.close();
  sdOk = false;
}

static void geoFields(char* buf, size_t cap, size_t* pos, const deck_geo_t& g) {
  uint8_t acc = g.hdop_x10 / 2 < 3 ? 3 : g.hdop_x10 / 2;
  *pos += snprintf(buf + *pos, cap - *pos, "%.7f,%.7f,%d,%u", g.lat_e7 / 1e7, g.lon_e7 / 1e7, g.alt_m, acc);
}

// Only geotagged sightings are written — WiGLE ignores rows without coordinates.
static void logWifi(const deck_wifi_obs_t& o) {
  if (!sdOk || !o.geo.fix) { noFixRows++; return; }
  char line[220], mac[18], ts[24];
  size_t pos = 0;
  fmtMac(mac, o.mac);
  fmtTime(ts, sizeof(ts), o.geo.utc);
  pos += snprintf(line, sizeof(line), "%s,", mac);
  pos = appendCsv(line, sizeof(line), pos, o.ssid, o.ssid_len);
  pos += snprintf(line + pos, sizeof(line) - pos, ",%s,%s,%u,%d,", wigleAuth(o.enc), ts, o.channel, o.rssi);
  geoFields(line, sizeof(line), &pos, o.geo);
  snprintf(line + pos, sizeof(line) - pos, ",WIFI");
  wigleFile.println(line);
  wigleRows++;
}

static void logBle(const deck_ble_obs_t& o) {
  if (!sdOk || !o.geo.fix) { noFixRows++; return; }
  char line[200], mac[18], ts[24];
  size_t pos = 0;
  fmtMac(mac, o.mac);
  fmtTime(ts, sizeof(ts), o.geo.utc);
  pos += snprintf(line, sizeof(line), "%s,", mac);
  pos = appendCsv(line, sizeof(line), pos, o.name, o.name_len);
  pos += snprintf(line + pos, sizeof(line) - pos, ",Misc [LE],%s,0,%d,", ts, o.rssi);
  geoFields(line, sizeof(line), &pos, o.geo);
  snprintf(line + pos, sizeof(line) - pos, ",BLE");
  wigleFile.println(line);
  wigleRows++;
}

static void logClient(const deck_wifi_obs_t& o) {
  if (!sdOk || !o.geo.fix) { noFixRows++; return; }
  char line[200], mac[18], ap[18], ts[24];
  size_t pos = 0;
  fmtMac(mac, o.mac);
  fmtMac(ap, o.ap_mac);
  fmtTime(ts, sizeof(ts), o.geo.utc);
  pos += snprintf(line, sizeof(line), "%s,%s,", mac, ap);
  pos = appendCsv(line, sizeof(line), pos, o.ssid, o.ssid_len);
  snprintf(line + pos, sizeof(line) - pos, ",%s,%u,%d,%.7f,%.7f,%u", ts, o.channel, o.rssi,
           o.geo.lat_e7 / 1e7, o.geo.lon_e7 / 1e7, o.flags);
  clientFile.println(line);
  clientRows++;
}

// ---------------------------------------------------------------------------------------
// Table upserts
// ---------------------------------------------------------------------------------------
static void noteGeo(const deck_geo_t& g) {
  if (g.fix) { lastGeo = g; lastGeoMs = millis(); }
}

// Finds `mac` in a table; if absent, takes a free slot or evicts the stalest one.
template <typename T>
static T* upsert(T* tab, int cap, int* count, const uint8_t* mac, bool* isNew) {
  int free = -1, oldest = 0;
  for (int i = 0; i < cap; i++) {
    if (!tab[i].used) { if (free < 0) free = i; continue; }
    if (memcmp(tab[i].mac, mac, 6) == 0) { *isNew = false; return &tab[i]; }
    if (tab[i].lastMs < tab[oldest].lastMs || !tab[oldest].used) oldest = i;
  }
  *isNew = true;
  int slot = free >= 0 ? free : oldest;
  if (free >= 0) (*count)++;
  memset(&tab[slot], 0, sizeof(T));
  tab[slot].used = true;
  memcpy(tab[slot].mac, mac, 6);
  return &tab[slot];
}

static void onWifiAp(const deck_wifi_obs_t& o) {
  noteGeo(o.geo);
  bool isNew;
  WifiRec* r = upsert(wifiTab, WIFI_MAX, &wifiN, o.mac, &isNew);
  r->rssi = o.rssi; r->ch = o.channel; r->enc = o.enc; r->flags = o.flags;
  if (o.ssid_len > 0) { memcpy(r->ssid, o.ssid, o.ssid_len); r->ssid[o.ssid_len] = '\0'; }
  r->lastMs = millis();
  r->hits++;
  logWifi(o);
}

static void onWifiClient(const deck_wifi_obs_t& o) {
  noteGeo(o.geo);
  bool isNew;
  ClientRec* r = upsert(clientTab, CLIENT_MAX, &clientN, o.mac, &isNew);
  r->rssi = o.rssi; r->ch = o.channel; r->flags = o.flags;
  static const uint8_t zero[6] = {0};
  if (memcmp(o.ap_mac, zero, 6) != 0) memcpy(r->ap, o.ap_mac, 6);
  if (o.ssid_len > 0) { memcpy(r->probe, o.ssid, o.ssid_len); r->probe[o.ssid_len] = '\0'; }
  r->lastMs = millis();
  logClient(o);
}

static void onBle(const deck_ble_obs_t& o) {
  noteGeo(o.geo);
  bool isNew;
  BleRec* r = upsert(bleTab, BLE_MAX, &bleN, o.mac, &isNew);
  r->rssi = o.rssi; r->flags = o.flags; r->mfg = o.mfg_id;
  if (o.name_len > 0) { memcpy(r->name, o.name, o.name_len); r->name[o.name_len] = '\0'; }
  r->lastMs = millis();
  r->hits++;
  logBle(o);
}

// ---------------------------------------------------------------------------------------
// Link handling
// ---------------------------------------------------------------------------------------
static void handleFrame(Link& l, uint8_t type, const uint8_t* p, uint8_t len) {
  l.framesWindow++;
  switch (type) {
    case DECK_MSG_HELLO:
      if (len == sizeof(deck_hello_t)) {
        deck_hello_t h; memcpy(&h, p, sizeof(h));
        l.seen = true; l.lastHelloMs = millis();
        l.kind = h.node_kind; l.fw = h.fw_version;
        l.nodeFrames = h.frames_total; l.nodeDropped = h.tx_dropped; l.nodeUptime = h.uptime_ms;
        noteGeo(h.geo);
      }
      break;
    case DECK_MSG_WIFI_AP:
      if (len == sizeof(deck_wifi_obs_t)) { deck_wifi_obs_t o; memcpy(&o, p, sizeof(o)); onWifiAp(o); }
      break;
    case DECK_MSG_WIFI_CLIENT:
      if (len == sizeof(deck_wifi_obs_t)) { deck_wifi_obs_t o; memcpy(&o, p, sizeof(o)); onWifiClient(o); }
      break;
    case DECK_MSG_BLE:
      if (len == sizeof(deck_ble_obs_t)) { deck_ble_obs_t o; memcpy(&o, p, sizeof(o)); onBle(o); }
      break;
    case DECK_MSG_STATS:
      if (len == sizeof(deck_stats_t)) {
        memcpy(&l.stats, p, sizeof(deck_stats_t));
        l.haveStats = true;
        for (int i = 0; i < 13; i++) chanSmooth[i] = (chanSmooth[i] * 7 + l.stats.chan_frames[i] * 3) / 10;
      }
      break;
  }
}

static void pollLink(Link& l) {
  int budget = 1024;  // bytes per call, so one chatty link can't starve the UI
  while (budget-- > 0 && l.port->available()) {
    if (deck_link_feed(&l.parser, (uint8_t)l.port->read()))
      handleFrame(l, l.parser.type, l.parser.payload, l.parser.len);
  }
  uint32_t now = millis();
  if (now - l.lastRateMs >= 1000) {
    l.fps = l.framesWindow;
    l.framesWindow = 0;
    l.lastRateMs = now;
  }
}

static bool nodeLive(const Link& l) { return l.seen && (millis() - l.lastHelloMs) < 3000; }

// ---------------------------------------------------------------------------------------
// UI
// ---------------------------------------------------------------------------------------
enum Page { PAGE_NETWORKS, PAGE_BLE, PAGE_CLIENTS, PAGE_STATUS, PAGE_COUNT };
enum Sort { SORT_RSSI, SORT_RECENT, SORT_COUNT };
static int page = PAGE_NETWORKS, sortMode = SORT_RSSI, scroll = 0;
static bool dirty = true;
static uint32_t lastRenderMs = 0;

static int idxBuf[WIFI_MAX];   // scratch for sorted views (largest table)

static int cmpWifi(const void* a, const void* b) {
  const WifiRec& x = wifiTab[*(const int*)a]; const WifiRec& y = wifiTab[*(const int*)b];
  return sortMode == SORT_RSSI ? (int)y.rssi - x.rssi : (int)(y.lastMs > x.lastMs) - (int)(y.lastMs < x.lastMs);
}
static int cmpBle(const void* a, const void* b) {
  const BleRec& x = bleTab[*(const int*)a]; const BleRec& y = bleTab[*(const int*)b];
  return sortMode == SORT_RSSI ? (int)y.rssi - x.rssi : (int)(y.lastMs > x.lastMs) - (int)(y.lastMs < x.lastMs);
}
static int cmpClient(const void* a, const void* b) {
  const ClientRec& x = clientTab[*(const int*)a]; const ClientRec& y = clientTab[*(const int*)b];
  return sortMode == SORT_RSSI ? (int)y.rssi - x.rssi : (int)(y.lastMs > x.lastMs) - (int)(y.lastMs < x.lastMs);
}

template <typename T>
static int collect(T* tab, int cap, int (*cmp)(const void*, const void*)) {
  int n = 0;
  for (int i = 0; i < cap; i++) if (tab[i].used) idxBuf[n++] = i;
  qsort(idxBuf, n, sizeof(int), cmp);
  return n;
}

static const char* nodeTag(const Link& l) { return nodeLive(l) ? "+" : (l.seen ? "!" : "-"); }

static void renderHeader() {
  char b[80];
  uint32_t now = millis();
  bool fix = lastGeo.fix && (now - lastGeoMs) < 5000;
  snprintf(b, sizeof(b), "GPS %s %2usat  SD %s  W%s B%s  %s", fix ? "FIX" : "---", lastGeo.sats,
           sdOk ? "ok" : "NO", nodeTag(wifiLink), nodeTag(bleLink), lowBattery ? "LOW BATTERY" : "");
  drawRow(0, b, lowBattery ? C_RED : (fix ? C_GREEN : C_YELLOW), C_HEAD);

  int ap5 = 0, trackers = 0, openN = 0;
  for (int i = 0; i < WIFI_MAX; i++) if (wifiTab[i].used) { if (wifiTab[i].ch > 14) ap5++; if (wifiTab[i].enc == DECK_ENC_OPEN) openN++; }
  for (int i = 0; i < BLE_MAX; i++) if (bleTab[i].used && (bleTab[i].flags & DECK_BLE_FLAG_TRACKER)) trackers++;
  snprintf(b, sizeof(b), "WiFi %d (5G %d, open %d)  BLE %d (trk %d)  Cli %d", wifiN, ap5, openN, bleN, trackers, clientN);
  drawRow(1, b, C_CYAN);
}

static void renderFooter() {
  char b[80];
  static const char* names[] = {"NETWORKS", "BLE", "CLIENTS", "STATUS"};
  snprintf(b, sizeof(b), "<%s> %s  log:%lu rows  nofix:%lu", names[page], sortMode == SORT_RSSI ? "by RSSI" : "recent",
           (unsigned long)wigleRows, (unsigned long)noFixRows);
  drawRow(ROWS - 1, b, C_GRAY, C_HEAD);
}

static void clampScroll(int n) {
  if (scroll > n - LIST_ROWS) scroll = n - LIST_ROWS;
  if (scroll < 0) scroll = 0;
}

static void renderNetworks() {
  int n = collect(wifiTab, WIFI_MAX, cmpWifi);
  clampScroll(n);
  drawRow(2, "RSSI  CH ENC   CLI SSID", C_YELLOW);
  uint32_t now = millis();
  for (int r = 0; r < LIST_ROWS; r++) {
    int row = LIST_TOP + r;
    if (scroll + r >= n) { drawRow(row, ""); continue; }
    const WifiRec& w = wifiTab[idxBuf[scroll + r]];
    int cli = 0;
    for (int i = 0; i < CLIENT_MAX; i++) if (clientTab[i].used && memcmp(clientTab[i].ap, w.mac, 6) == 0) cli++;
    char b[80];
    snprintf(b, sizeof(b), "%4d %3u %-5s %3d %s%s", w.rssi, w.ch, encName(w.enc), cli,
             (w.flags & DECK_WIFI_FLAG_HIDDEN) ? "<hidden>" : "", w.ssid);
    uint16_t col = (now - w.lastMs > 60000) ? C_GRAY : (w.enc == DECK_ENC_OPEN ? C_RED : (w.enc == DECK_ENC_WEP ? C_ORANGE : C_GREEN));
    drawRow(row, b, col);
  }
}

static void renderBle() {
  int n = collect(bleTab, BLE_MAX, cmpBle);
  clampScroll(n);
  drawRow(2, "RSSI MFG  ADDRESS            NAME", C_YELLOW);
  uint32_t now = millis();
  for (int r = 0; r < LIST_ROWS; r++) {
    int row = LIST_TOP + r;
    if (scroll + r >= n) { drawRow(row, ""); continue; }
    const BleRec& d = bleTab[idxBuf[scroll + r]];
    char mac[18], b[80];
    fmtMac(mac, d.mac);
    snprintf(b, sizeof(b), "%4d %04X %s %s%s", d.rssi, d.mfg, mac, (d.flags & DECK_BLE_FLAG_TRACKER) ? "[TRK] " : "", d.name);
    uint16_t col = (d.flags & DECK_BLE_FLAG_TRACKER) ? C_RED : ((now - d.lastMs > 60000) ? C_GRAY : C_GREEN);
    drawRow(row, b, col);
  }
}

static void renderClients() {
  int n = collect(clientTab, CLIENT_MAX, cmpClient);
  clampScroll(n);
  drawRow(2, "RSSI  CH MAC               AP / PROBING", C_YELLOW);
  uint32_t now = millis();
  static const uint8_t zero[6] = {0};
  for (int r = 0; r < LIST_ROWS; r++) {
    int row = LIST_TOP + r;
    if (scroll + r >= n) { drawRow(row, ""); continue; }
    const ClientRec& c = clientTab[idxBuf[scroll + r]];
    char mac[18], b[80];
    fmtMac(mac, c.mac);
    if (memcmp(c.ap, zero, 6) != 0) {
      const char* apName = "";
      for (int i = 0; i < WIFI_MAX; i++) if (wifiTab[i].used && memcmp(wifiTab[i].mac, c.ap, 6) == 0) { apName = wifiTab[i].ssid; break; }
      snprintf(b, sizeof(b), "%4d %3u %s -> %s", c.rssi, c.ch, mac, apName[0] ? apName : "(ap)");
    } else {
      snprintf(b, sizeof(b), "%4d %3u %s ? %s", c.rssi, c.ch, mac, c.probe);
    }
    drawRow(row, b, (now - c.lastMs > 60000) ? C_GRAY : C_GREEN);
  }
}

static void nodeLine(int row, const char* name, const Link& l) {
  char b[80];
  if (!l.seen) snprintf(b, sizeof(b), "%s: no data yet", name);
  else snprintf(b, sizeof(b), "%s: %s up %lus  fw%u  fps %u  seen %lu  drop %lu  crc %lu", name,
                nodeLive(l) ? "LIVE" : "STALE", (unsigned long)(l.nodeUptime / 1000), l.fw, l.fps,
                (unsigned long)l.nodeFrames, (unsigned long)l.nodeDropped, (unsigned long)l.parser.crc_errors);
  drawRow(row, b, nodeLive(l) ? C_GREEN : C_RED);
}

static void renderStatus() {
  drawRow(2, "STATUS", C_YELLOW);
  nodeLine(3, "WiFi", wifiLink);
  nodeLine(4, "BLE ", bleLink);
  char b[80];
  snprintf(b, sizeof(b), "lat %.5f lon %.5f alt %dm hdop %.1f", lastGeo.lat_e7 / 1e7, lastGeo.lon_e7 / 1e7, lastGeo.alt_m, lastGeo.hdop_x10 / 10.0);
  drawRow(5, b);
  snprintf(b, sizeof(b), "SD: %s", sdOk ? wigleName : "not mounted / no card");
  drawRow(6, b, sdOk ? C_FG : C_RED);
  snprintf(b, sizeof(b), "rows: wifi/ble %lu  clients %lu  no-fix skipped %lu", (unsigned long)wigleRows, (unsigned long)clientRows, (unsigned long)noFixRows);
  drawRow(7, b);
  if (wifiLink.haveStats) {
    snprintf(b, sizeof(b), "deauth %lu  disassoc %lu  mgmt %lu  5GHz/2s %u", (unsigned long)wifiLink.stats.deauth,
             (unsigned long)wifiLink.stats.disassoc, (unsigned long)wifiLink.stats.mgmt_frames, wifiLink.stats.five_ghz_frames);
    drawRow(8, b, wifiLink.stats.deauth > 20 ? C_RED : C_FG);
  } else drawRow(8, "");
  drawRow(9, "2.4 GHz channel activity (frames / 2s)", C_YELLOW);

  // Bars: rows 10..22 are cleared and redrawn as graphics.
  const int top = 10 * ROW_H, height = 12 * ROW_H;
  tft.fillRect(0, top, 320, height, C_BG);
  uint16_t maxv = 1;
  for (int i = 0; i < 13; i++) if (chanSmooth[i] > maxv) maxv = chanSmooth[i];
  for (int i = 0; i < 13; i++) {
    int h = (int)((uint32_t)chanSmooth[i] * (height - 24) / maxv);
    int x = 6 + i * 24;
    tft.fillRect(x, top + height - 12 - h, 18, h, (i == 0 || i == 5 || i == 10) ? C_GREEN : C_CYAN);
    tft.setCursor(x + (i < 9 ? 6 : 3), top + height - 9);
    tft.setTextColor(C_GRAY, C_BG);
    tft.print(i + 1);
  }
}
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
void loop() {
  pollLink(wifiLink);
  pollLink(bleLink);
  pollButtons();

  uint32_t now = millis();

  if (!lowBattery && digitalRead(PIN_BAT_LOW) == LOW) {
    lowBattery = true;
    closeLogs();            // flush and close before the battery cuts out
    dirty = true;
  }
  if (sdOk && now - lastFlushMs >= 5000) {
    lastFlushMs = now;
    wigleFile.flush();
    clientFile.flush();
  }

  if (dirty || now - lastRenderMs >= 500) {
    dirty = false;
    lastRenderMs = now;
    render();
  }
}

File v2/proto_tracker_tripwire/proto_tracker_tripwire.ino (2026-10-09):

// CyberDeck v2 — bench prototype: "Tracker Tripwire"
//
// A standalone counter-surveillance BLE scanner that runs on the HUB BOARD ALONE
// (ESP32-S3-DevKitC-1 + 2.8" ILI9341) with a breadboarded active buzzer and LED.
// No nodes, no GPS, no PCB needed. It proves out the Tier-1 (tracker detection +
// persistence scoring) and Tier-2 (LED + buzzer alert) counter-surveillance features
// before any of that goes into the real split hub/node firmware.
//
// What it does:
//   - Scans BLE continuously and classifies each device (AirTag/Find My, Tile,
//     Samsung SmartTag, or generic).
//   - Scores PERSISTENCE: how long a given MAC keeps reappearing. With no GPS yet,
//     "sticky over time" is the stand-in for "it's moving with me."
//   - ALERTS (red banner + LED + buzzer chirp) when a *tracker-class* device has been
//     sticky past STICKY_MS. BOOT button (GPIO0) acknowledges/snoozes the buzzer.
//   - Shows a live, colour-coded list on the TFT, sorted by persistence.
//
// Board:     ESP32-S3 Dev Module ("USB CDC On Boot: Enabled"). BLE is built in.
// Libraries: Adafruit GFX, Adafruit ILI9341 (BLE comes with the ESP32 core).
//
// Wiring (matches docs/PCB-BOM-AND-NETLIST.md so pins carry over to the real hub):
//   ILI9341:  SCK=GPIO12  MOSI=GPIO11  MISO=GPIO13  CS=GPIO10  DC=GPIO9  RST=GPIO8  LED/BL=GPIO7(+3V3)
//   Buzzer:   GPIO18 -> active buzzer(+),  buzzer(-) -> GND          (J_SPARE pin)
//   LED:      GPIO21 -> 220ohm -> LED(+),  LED(-) -> GND             (J_SPARE pin)
//   Ack btn:  the on-board BOOT button (GPIO0), active low           (no wiring needed)

#include <SPI.h>
#include <Adafruit_GFX.h>
#include <Adafruit_ILI9341.h>
#include <BLEDevice.h>
#include <BLEUtils.h>
#include <BLEScan.h>
#include <BLEAdvertisedDevice.h>

// ---------------------------------------------------------------------------------------
// Pins (same as the real hub so this ports cleanly)
// ---------------------------------------------------------------------------------------
static const int PIN_SCLK = 12, PIN_MOSI = 11, PIN_MISO = 13;
static const int PIN_TFT_CS = 10, PIN_TFT_DC = 9, PIN_TFT_RST = 8, PIN_TFT_BL = 7;
static const int PIN_BUZZER = 18;
static const int PIN_LED    = 21;
static const int PIN_ACK    = 0;    // BOOT button, active low

// ---------------------------------------------------------------------------------------
// Tunables
// ---------------------------------------------------------------------------------------
// How long a tracker must keep reappearing before it counts as "following you" and fires
// the alert. 45 s is friendly for a bench/walk test; raise to a few minutes for real use
// to cut false alarms from trackers that are simply parked near you (a neighbour's AirTag).
static const uint32_t STICKY_MS      = 45000;
static const uint32_t FORGET_MS      = 120000;  // drop a device not seen for this long
static const uint32_t SNOOZE_MS      = 60000;   // BOOT press silences the buzzer this long
static const uint32_t CHIRP_GAP_MS   = 4000;    // min gap between buzzer chirps
static const int      TABLE_MAX      = 150;

// Defined up here (before any function) so Arduino's auto-generated prototypes, which are
// hoisted to the top of the file, can see the type.
struct Dev {
  bool     used;
  uint8_t  mac[6];
  uint8_t  cls;
  bool     randomAddr;
  int8_t   bestRssi;
  int8_t   lastRssi;
  uint32_t firstMs;     // first time ever heard  -> persistence = lastMs - firstMs
  uint32_t lastMs;      // most recent hit
  uint16_t hits;
  bool     alerted;     // buzzer already fired for this one
  char     name[20];
};

// ---------------------------------------------------------------------------------------
// Device classes
// ---------------------------------------------------------------------------------------
enum { CLS_NONE = 0, CLS_FINDMY, CLS_TILE, CLS_SMARTTAG, CLS_GENERIC };
static const char* clsName(uint8_t c) {
  switch (c) {
    case CLS_FINDMY:   return "FindMy/AirTag";
    case CLS_TILE:     return "Tile";
    case CLS_SMARTTAG: return "SmartTag";
    case CLS_GENERIC:  return "device";
    default:           return "-";
  }
}
static bool isTracker(uint8_t c) { return c == CLS_FINDMY || c == CLS_TILE || c == CLS_SMARTTAG; }

// ---------------------------------------------------------------------------------------
// Device table
// ---------------------------------------------------------------------------------------
static Dev      tab[TABLE_MAX];
static int      devCount = 0;
static uint32_t alertsTotal = 0;

static portMUX_TYPE tabMux = portMUX_INITIALIZER_UNLOCKED;  // scan runs in the BLE task

static Dev* findOrAdd(const uint8_t* mac, bool* isNew) {
  int free = -1, oldest = 0;
  for (int i = 0; i < TABLE_MAX; i++) {
    if (!tab[i].used) { if (free < 0) free = i; continue; }
    if (memcmp(tab[i].mac, mac, 6) == 0) { *isNew = false; return &tab[i]; }
    if (tab[i].lastMs < tab[oldest].lastMs || !tab[oldest].used) oldest = i;
  }
  *isNew = true;
  int slot = free >= 0 ? free : oldest;      // evict the stalest if the table is full
  if (free >= 0) devCount++;
  memset(&tab[slot], 0, sizeof(Dev));
  tab[slot].used = true;
  memcpy(tab[slot].mac, mac, 6);
  return &tab[slot];
}

static uint32_t persistence(const Dev& d) { return d.lastMs - d.firstMs; }
static bool     sticky(const Dev& d)      { return persistence(d) >= STICKY_MS; }
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

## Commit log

2026-08-25 Initial commit: CyberDeck firmware and docs (components 1-5)
    WiFi sniffer, BLE hunter, SubGHz control, hub console firmware plus
    integration/shared header and project docs, imported ahead of the
    ESP-NOW consolidation redesign (dropping the Arduino Uno node).
2026-08-25 Migrate sub-GHz control from Arduino Uno to ESP32-C3 node over ESP-NOW
    Drops the Uno + big LCD control surface entirely. Sub-GHz sensing
    (rc-switch decode + raw pulse fallback) now runs on a third ESP32-C3
    node reporting deck_report_t (node_id=3) to the hub via ESP-NOW
    broadcast, matching the wifi/ble nodes. Display/menu/control logic
    moves to the hub console; hub's now-dead UART receiver path is removed.
    deck_report_t gains subghz_code/subghz_pulse_len/subghz_repeats fields.
    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
2026-08-25 Flesh out top-level README with project overview and architecture
    Was a single-line title. Adds scope, ESP-NOW-consolidated architecture
    diagram, component status table, and doc links, matching the current
    state described in COMPONENTS.md.
2026-08-25 Wire WiFi sniffer into ESP-NOW; fix hub MAC race; update hub README
    - wifi_sniffer.ino: switch WIFI_MODE_NULL -> WIFI_MODE_STA (required for
    ESP-NOW) and send a deck_report_t (node_id=1) broadcast on each newly
    discovered AP/prober. Confirmed live on real hardware: 102 mgmt frames,
    10 distinct SSIDs/probers captured cleanly.
    - hub_console.ino: WiFi.macAddress() read all-zero when queried
    immediately after WiFi.mode(WIFI_STA) — driver init is asynchronous.
    Added a 100ms delay before the read; confirmed against eFuse MAC on
    real hardware (a4:f0:0f:81:e6:cc). Hub also confirmed booting clean
    and cycling its 5 dashboard screens on synthetic data.
    - 04-hub-console/README.md: refle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
2026-08-25 Wire BLE hunter into ESP-NOW (node_id=2)
    Reports each newly-discovered device and each flagged transition
    (persistence threshold or rotating-MAC/Find My match) to the hub as
    deck_report_t, broadcast — same pattern as the wifi sniffer node.
    Confirmed live on real hardware: boots clean, no crash despite tight
    flash headroom (94%, NimBLE + WiFi/ESP-NOW + Adafruit graphics
    together), and this run gave the first live confirmation of 2.4
    (rotating-MAC/Find My heuristic) actually firing on a real device.
2026-09-03 Fix ESP-NOW send reliability, drop sub-ghz from hub, add pinout/PCB docs
    Root cause of dropped wifi reports: esp_wifi_set_channel() was restoring
    the scan channel immediately after esp_now_send(), before the packet had
    actually gone out over the air, silently dropping most sends. Fixed via
    a bounded wait for the send-completion callback (espNowSendAndWait()) in
    both wifi_sniffer.ino and wifi_spectrum.ino, plus batching newly-discovered
    networks/devices into one deck_wifi_batch_t packet instead of one send per
    discovery. Also added randomized send-timing jitter so two field nodes
    powered on together don't stay phase-locked and collide every cycle.
    Hub console: replaced the 5-screen auto-cycl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
2026-09-20 Add v2 wired-UART firmware and PCB design docs
    Fresh-start redesign: receive-only C5 (WiFi 2.4+5GHz) and C6 (BLE) nodes
    report over wired UART to an ESP32-S3 hub with GPS-tagged WiGLE CSV logging.
    Adds the v2/ firmware (uncompiled, unflashed) plus overview, design, and
    BOM/netlist docs for the KiCad board.
    [deck_node_core.h, hub.ino, node_ble.ino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]
2026-09-25 Clean up for v2: remove v1 build, consolidate docs, add Pages deploy
    - Remove the v1 ESP-NOW build (01-05 components, COMPONENTS.md) and its
    docs (PINOUTS, 1732S019 datasheet, old plan and sourcing notes).
    The previous tree is tagged v1-espnow-archive.
    - Merge PCB-DESIGN.md and V2-OVERVIEW.md into docs/OVERVIEW.md, updated
    for the nde3d parts (C3 PRO Mini, H2 SuperMini, IP5310 + 18650).
    - Rewrite README for v2; point firmware comments and v2/README at the
    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
    [CyberDeckv1.kicad_pcb, CyberDeckv1.kicad_sch]
2026-10-09 Docs: clamshell build plan with S3 hub and 2S power, new parts list
    Add hardware-layout.md/.svg for the 22 x 22 cm clamshell case: budget v1
    with the ESP32-S3 as hub, Raspberry Pi 5 as a later phase, 2S2P battery
    system with DC-jack charging, and the nde3d parts list. Update OVERVIEW.md
    to the new plan and mark the single-PCB BOM as shelved.
2026-10-09 Add bench prototypes, case photos and prototype references
    Add the counter-surveillance bench prototypes (C3 WiFi readout, UNO
    readout, UNO link analyzer, S3 tracker tripwire) with their README
    section and wiring page, the empty-case photos used for the layout
    plan, the ESP32-1732S019 datasheet, and the KiCad project settings.
2026-10-09 Docs: name each board and add BLE-SCAN (ESP32-1732S019) spec
    Add a Board names table (HUB, READOUT, BLE-SCAN, WIFI-NODE, STATUS) to
    hardware-layout.md and rewrite the nde3d ESP32-1732S019 product sheet as
    a markdown spec with planned deck wiring.
2026-10-09 Docs: redraw hardware layout for budget v1
    Show the ESP32-S3 hub build in hardware-layout.svg: named boards in the
    lid, blank plate with GPS in the 5" slot, HUB and WIFI-NODE bays under
    the deck, DC-jack charging and the raised-deck depth stack. Align the
    caption and bay locations in hardware-layout.md.
2026-10-09 Build page and READMEs for the clamshell build
    Add docs/build-page.html as the GitHub Pages front page (boards, layout,
    parts checklist, power, wiring, build order) and deploy the layout SVG
    with it; keep the shelved PCB page as pcb-v2.html. Rewrite v2/README.md
    and the root README for the named boards and budget v1 plan. Restore the
    GPS fan-out to both nodes in the docs to match the node firmware.
2026-10-31 Redesign the clamshell build around the Pi 5 and 7-inch panel
    Add a parametric 8-block printed filler for the 25 mm deep case halves,
    with generated placement and wiring drawings. Update the build page,
    docs and shopping list for the Raspberry Pi 5 4GB hub, and replace the
    dead nde3d links with prices and stock checked on 2026-10-31.
2026-11-02 Drop the CC1101 for an RTL-SDR and plan the hub software
    The RTL-SDR V4 on the Pi's USB takes the CC1101's lid bay and antenna
    channel, and rtl_433 decodes far more 433 MHz devices, including tyre
    sensors for spotting repeat cars. The SPI pins are freed. The build page
    gains a six-stage hub software plan (Kismet ingest, following detection,
    threat alerts, map and phone dashboard, watch sync, rtl_433). STATUS is
    now a removable watch. Print files are unchanged; only labels and the
    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
2026-11-03 Redraw the wiring diagram for the ESP32-DIV v1 hub
    The Pi 5 hub is dropped. The wiring drawing now shows the ESP32-WROOM-32U
    running ESP32-DIV v1 firmware: ILI9341 TFT, touch and SD, PCF8574
    buttons, NEO-7M GPS, U.FL antenna and the 1S3P power chain. Pins are taken
    from the firmware's shared.h and User_Setup v1.h.
    The drawing comes from its own script, cad/wiring/generate_wiring.py,
    so the case filler generator no longer writes wiring.svg. The build page
    wiring section and hardware-layout.md say the rest of the docs still
    describe the Pi 5 build.
2026-11-03 Rewrite the docs for the ESP32-DIV v1 build
    The Pi 5 hub, 7-inch panel and RTL-SDR are dropped. The docs now describe
    the kit as built: an ESP32-DIV v1-style HUB (ESP32-WROOM-32U, 2.4" ILI9341
    touch/SD, PCF8574 buttons, NEO-7M GPS, router antenna), the working
    WIFI-NODE + READOUT pair, and the STATUS watch, all on a 1S3P 18650 pack
    and a 5V 2A boost module.
    - README, OVERVIEW and hardware-layout: new architecture, board names,
    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
2026-11-07 Split the HUB wiring into ESP32 + touchscreen and protoboard drawings
    The GPS, PCF8574 and buttons now sit on an UNO proto shield joined to the
    ESP32 by a 6-wire cable (J1). Add an overview drawing of the two parts and
    the cable, a pin-level protoboard drawing, and redraw the ESP32 +
    touchscreen drawing with the J1 connector. Update the build page, README
    and hardware layout to match.
2026-11-07 Publish all wiring SVGs to GitHub Pages
    The workflow copied only wiring.svg, so wiring-overview.svg and
    wiring-protoboard.svg returned 404 on the build page.
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2026-11-13 Add SENTINEL passive watcher firmware and module naming scheme
    Repurpose the freed C3+UNO pair (after the orchestrator moves to SPECTRE)
    into SENTINEL: a standalone, never-transmit counter-surveillance watcher.
    One C3 radio round-robins a WiFi promiscuous window (feeds tail + attack
    detection) and a passive BLE scan window (feeds tracker-tag detection);
    persistence (a per-device sweep counter) drives the follow/tail alerts,
    with results + a red alert LED on the UNO's 3.5" screen. Reuses the
    orchestrator's promiscuous/parse/table/BLE-classify code; drops all
    active/TX, BLE-control, HID and evil-portal. Compile-verified: C3 55%
    flash, UNO 55% flash.
    Also introduce fixed per-module names (SPEC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
2026-11-13 Drop button matrix and protoboard from the HUB; add in-case module layout
    - SPECTRE is driven by the CONSOLE phone app over BLE (and the touchscreen);
    the PCF8574 + 5-button matrix is removed, freeing GPIO 21/22.
    - The GPS wires straight to the ESP32 (no protoboard, no J1 cable).
    Regenerate wiring.svg as a single ESP32 + TFT + GPS diagram and drop the
    overview and protoboard drawings.
    - Update build-page.html, hardware-layout.md and OVERVIEW.md: pin table,
    rules, bring-up/build order, parts list (remove PCF8574 + buttons), and a
    decision-log row.
    - Replace case-layout.svg with the in-case module plan: the power section
    (powerbank + 3x 18650 + charging station) fills the bottom, t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
